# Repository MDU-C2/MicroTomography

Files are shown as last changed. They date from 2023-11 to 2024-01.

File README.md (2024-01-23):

# Microwave Imaging



## Install python packages from requirements.txt

Run the command

```console
pip install -r requirements.txt
```

In the command prompt

# Setup
First, make sure the following is powered on and set up as described.
## Router
- Connect the router to the eduroam network using an ethernet cable from the wall to the router.
- Connect the Raspberry Pi to the router using an ethernet cable.
- Connect the Network analyzer to the router using an ethernet cable.
- Connect the robot controller to the ruter using an ethernet cable.
- Power on the router by connecting it to a power outlet.

## Raspberry Pi 4
Set up the Raspberry pi:
- Connect the screen to the Pi using a micro-HDMI to HDMI cable.
- Connect the mouse and keyboard to the Pi using the USB-A conncetions.
- Connect a ethernet cable from the raspberry Pi to the router.
- Connect the USB-A side of the laser connection to a USB-A port on the Raspberry Pi
- Power on the Raspberry Pi by connecting the USB-C side of a Raspberry Pi 4 adapter to the Raspberry pi and the other side to a power outlet.

## Network Analyzer
- Connect the Microwave applicator to channel 2 on the network analyzer.
- Connect the Microwave reciever to channel 3 on the network analyzer.
- Connect the Lan 1 port of the network analyzer to the router using a ethernet cable.
- Conncet the power cable from the network analyzer to a power outlet.
- Make sure the switch by the power input is fliped to the on state.
- Power on the network analyser by pressing the on button in the lower left corner of the front panel. 

## Robot controller
- Connect the robot controller to the router using an ethernet cable.
- Connect a power cable from the robot controller to a power outlet.
- Power on the robot controller.

# Starting the program
There are two program to run. One is a terminal program and the other is a GUI, however, both lets you use the whole system. Both are located in the folder repositories/MicroTomography.

## Starting the terminal program
To start the terminal program follow these simple steps.
1. Follow the setup described above.
2. Locate the repositories/MicroTomography folder in the raspberry pi 4. This can be done by opening a new terminal window and typing `cd repositories/MicroTomography`.
3. Start the program main.py by typing `python3.10 Main.py` in the terminal window.

## Starting the GUI
To start the GUI follow these simple steps.
1. Follow the setup described above.
2. Locate the repositories/MicroTomography folder in the raspberry pi 4. This can be done by opening a new terminal window and typing `cd repositories/MicroTomography`.
3. Start the program main.py by typing `python3.10 MainProgram.py` in the terminal window.

# Move linear actuator and take measurements
To only move the linear actuator and take measurements at the current configuration of the robot run the file *take_measurements.py* where you get a prompt asking what you want to do. It saves the microwave data in both s2p and csv format.

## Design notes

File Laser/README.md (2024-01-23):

# Using the laser
## Setup
To use the laser simply connect the USB to the computer and take note of what port you connected to (on the raspberry pi it is usually /dev/ttyUSB0). You can then connect to the laser by calling the class:
``` python
from laser.optoNCDT1402 import optoNCDT1402

laser = optoNCDT1402("/dev/ttyUSB0")
```
This connects the laser to the computer via serial.
## Take measurements
To measure the distance with the laser, first make sure that it is on by connecting the laser off pin to ground then calling the measure() method:
``` python
from laser.optoNCDT1402 import optoNCDT1402

laser = optoNCDT1402("/dev/ttyUSB0")

distance = laser.measure()
```
This can easily be modified to takea measurement value every second:
``` python
from laser.optoNCDT1402 import optoNCDT1402
from time import sleep

laser = optoNCDT1402("/dev/ttyUSB0")
while True:
    distance = laser.measure()
    sleep(1)
```

## Get info and change moving average
Information about the laser can be recieved using getInfo():
``` python
from laser.optoNCDT1402 import optoNCDT1402

laser = optoNCDT1402("/dev/ttyUSB0")
print(laser.getInfo())
```
The internal moving average can also be changed by calling the setMovingAverage() method:
``` python
from laser.optoNCDT1402 import optoNCDT1402

laser = optoNCDT1402("/dev/ttyUSB0")
laser.setMovingAverage(10)
print(laser.getInfo())
```
The Filter Type should then read moving average and the Filter Number should read 10.

# optoNCDT1402-100 Class documentation
This document explains how to use the distance measurement sensor optoNCDT1402 and all of its functionalities.
The class needs the library pyserial 3.15. To install the library run the command
``` console
pip install pyserial
```
or the command
``` console
pip install -r requirements.txt
```
in the command prompt.

## Initialize class:
To initialize the class write optoNCDT1402() if the default parameters are correct. If not, the parameters comPort and noMeasurements can be added to the class call such that it becomes optoNCDT1402(comPort, noMeasurements).

### Parameters

**comPort:** A string with the name of the port on the computer the laser is connected to.

**noMeasurements:** The number of measurements to be averaged over before returning the distance. If you do not require averaging set it to 1 or leave it blank.
## Get laser info:
In the class you can retrieve the information stored in the laser. It will return in the form of a string and look something like

>ILD 1402: Standard <br> 
>A/N: 4120154 <br>
>O/N: 000 <br>
>S/N: 1234570 <br>
>MR: 50 <br>
>SoftVer: 1.001.796 <br> 
>BootVer: 1.001.16 <br>
>Date: 09/01/23 <br>
>Out Channel: analog | digital <br>
>Analog Error: last value | error value | error value after cycles xx //xx is 2 up to 99 <br>
>Filter Type: moving average | median<br>
>Filter Number: xx //with moving average xx is 1 up to 128, with median xx is 7, 5, 7 or 9<br>
>Scanrate: xxHz //xx is 1500 Hz, 1000 Hz, 750 Hz, 375 Hz<br> 
>type of digital output: binary | ascii <br>
>mode of analog/digital output: continuous | time | trigger<br>
>output time: xx //xx is time in ms 1<br>
>key status: unlock | lock | auto lock <br>
>mode of save setting: no save | save at each time<br> 
>mode of extern input: as teach in | as output trigger<br>
>peak searching: global maximum | first peak | last peak <br>
>Teach value 1: xx //xx is 1.0 up to 16368.0 <br>
>Teach value 2: xx //xx is 1.0 up to 16368.0<br>

To get the string, call optoNCDT1402.getInfo()

## Set moving average:
The laser have a function to set the Filter Type to moving average and the Filter Number. This means that a moving average of the last xx measurements are returned from the laser. This function can be set with the optoNCDT1402.setMovingAverage() call and returns True if it succeded or False if it did not. The parameter averagingNumber can be set to an integer to set the number of measurements to average over in the moving average.

### Parameters

**averagingNumber:** An int defining the number of measurements to average over in the laser

## Turn laser on/off:
The laser can be turned on or off from the class using the calls optoNCDT1402.laserOff() to turn off and optoNCDT1402.laserOn() to turn on. They both return True if it worked and False if it did not. The small black cable called laser_off needs to be grounded for the calls to work properly.

**The calls are volitile! The laser will always be on after disconnecting power!**

<span style = "color:red">**ALWAYS ASSUME THE LASER TO BE ON WHEN STARTING. DO NOT LOOK INTO THE LASER**</span>

## Get measurements:
To get measurements from the laser, call optoNCDT1402.measure(). This will start the measuring process by collecting two bytes from the laser and combining them to one difital number. The function then converts it to a distance in mm or an error string based on that digital number.

### Returns
Error or distance in mm

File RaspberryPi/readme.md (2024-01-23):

# Raspberry Pi

The following code will control the transistor which is connected to a GPIO pin on the Raspberry Pi. Depending to which GPIO pin the transistor is connected to the code may have to be mmodified to match the pin number.

> **_NOTE:_**  All code will be executed on the Raspberry Pi. The following code is used for controlling devices connected to the GPIO pins of Raspberry Pi.

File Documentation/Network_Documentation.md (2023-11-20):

# Network

The following documentation provides information regarding the network setup of the system. The network uses the 192.168.0.0/24 range

## Static IP addresses

Devices which are stationary to the system receives static IP addresses. Below is a list of the current devices allocated a static IP address.

* Wireless router: 192.168.0.1
* ABB Singe-Arm YuMi: 192.168.0.50
* Raspberry Pi: 192.168.0.51
* Vector Network Analyzer: 192.168.0.70

## Dynamic IP addresses

Clients which are not mentioned in the section above will receive an IP address from the range of 192.168.0.100-199

## WiFi

It is possible to connect to the network via WiFi

SSID: "*MW*"

Password: "*!UseThisPassword* "

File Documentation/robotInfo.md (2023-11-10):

# Robot Arm documentation - IRB 14050 Single Arm YuMi

This document is for information regarding the robotarm.

## Upload script to YuMi robot arm

Currently a slightly modified script of *SERVER.mod* is used , which can be found at <https://github.com/robotics/open_abb>. The modification done was from
*PERS string ipController:= "127.0.0.1";*
to
*PERS string ipController:= "192.168.0.100";* (the IP address will vary depending the on the address it is given by the DHCP server)

To upload the script to the YuMi controller you need RobotStudio. Ensure you are either:

* Connected to the YuMi via the MGMT port and that your PC has an IP address of 192.168.125.[2-254]. YuMi has an IP address of 192.168.125.1 which is static. Check connection from PC by opening a terminal and type "*ping 192.168.125.1*". If connection is established ping will be successful.
* Or connect the YuMi and your PC to a router that supports DHCP. When connecting the YuMi to router, use the WAN port on the YuMi. Find the allocated IP address of the YuMi by navigating to Settings -> Network settings on the YuMi FlexPendant. Check connection from PC by opening a terminal and ping the IP address found on the FlexPendant.

When connection has been established, open RobotStudio:

1. File -> Online -> One Click Connect
2. Open tab RAPID -> Program -> Load Module, upload "*SERVER.mod*". This will upload the module to the YuMi controller.
3. On the FlexPendant, navigate to *Operate*, select the uploaded file and press the physical *Play button* on the FlexPendant

## Joints range of motion

| Joint | Range (degrees) |
| ---  | --- |
| 1 | (-168.5) - 168.5  |
| 2 | (-143.51) - 43.49 |
| 3 | (-123.5) - 79.96  |
| 4 | (-289.95) - 289.84|
| 5 | (-87.62)  - 137.95|
| 6 | (-228.71) - 228.72|
| 7 | (-168.35) - 168.23|

## How to simulate the *IRB 14050 - YuMi* in *RobotStudio*

This section describes how the robot arm can be simulated in *RobotStudio* which is a preferable initial step for programming and testing the robot arm. To simulate the robot arm, open *RobotStudio* and perform the following steps:

1. Create a new project by *File -> New -> Station*.
2. Ensure that RobotWare 7.10 is installed. If not, navigate to the *Add-Ins* tab and find the package *RobotWare 7.10.0* and download it.
3. Create a new virtual controller by *Home -> Virtual Controller -> New Controller*
4. Select the *IRB 14050 0.5kg 0.5m* as the **Robot model** and choose the latest **RobotWare**. You can leave the rest unchanged, change the **Location** if you want to save the new controller in a different location than the default location.
5. When a pop-up window appears, select *IRB14050_0.5_0.5__03* and press **OK**.
6. To upload *RAPID* code to the virtual controller navigate to *RAPID -> Program -> Load Module* and upload the *RAPID* code you wish to execute. If you receive Errors after you have uploaded the code it might be due to there existing to *MAIN* files. In the tree structure to the left remove any *RAPID* files which you have not uploaded. To check if any errors persist press *RAPID -> Check Program* and check the log.
7. To start the simulation navigate to *Simulation -> Play*. *Do note that the simulation will not start if errors exist in the code
8. If you are sending commands to the robot arm via socket communication like this project. Ensure that the IP address in the *RAPID* and *Python* code are set to *127.0.0.1*  

## Potential issues and how to solve them

This section is for listing issues that has occured during the use of the arm whilst working with it during this project. Find potential issues here and how they were solved.

### Socket error

If the FlexPendant reports that you have a socket connection error which prevents you from connecting to the socket, the internal firewall of the Controller might be blocking it. This error may occur if you factory reset the controller. To fix the issue, try the following.

1. Connect your PC to the MGMT port of the controller and change your IP address to an address in the following range *192.168.125.[2-254]* with a subnet mask of *255.255.255.0*
2. Open *RobotStudio* and connect to the controller as specified in Section: **Upload script to YuMi robot arm**.
3. In *RobotStudio*, open *Controller -> Configuration -> Communication*. Open the tab *Firewall* and ensure that the desired connections are allowed through the Firewall. After changes are applied the controller needs to be restarted for the changes to be applied

### TimeoutError: timed out

If you are trying to connect to the robot via a TCP socket and receive a timeout error it is most likely due to networking issues. Check the following if you encounter this issue.

* Open the terminal on your computer and ensure you can ping the IP address of the controller.
* Make sure the IP address set in the *RAPID* code is the same as the IP address of the controller.
* Make sure the IP address set in the *Python* code is the same as the IP address of the controller.

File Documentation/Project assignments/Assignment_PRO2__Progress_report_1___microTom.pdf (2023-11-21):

# Progress Report 1-µTomography

Ihsan Haidari∗

, Joel Josefsson†

, Märta Krönström‡

, Dennis Landré§

, Filip Lindhe¶
, Jiantao Shen∥
, Samuel Wågbrant∗∗
School of Innovation, Design and Engineering Mälardalens University, Västerås, Sweden Email: ∗mhi19005, †

jjn17015, ‡mkm18003, §dle18001, ¶fle16001, ∥ jsn19012, ∗∗swt19001@student.mdu.se

I. PROJECT INFORMATION
Project title | Client Sponsors | Project Team Leaders | Project Date
Microwave Imaging for Breast Cancer Detection: A Non-Contacting Approach | Nikola Petrovic and Cristoph Salomon | Software: Märta Krönström Hardware: Dennis Landré | 2023-10-30
Name | Title | Responsibilities
Dennis Landré | Hardware Team Leader | Ensuring the project meets hardware requirements. 3D Modeling.
Ihsan Haidari | Hardware Developer | Responsible for the platform and sender platform.
Märta Krönström | Software Team Leader

Ensuring the project
meets software
requirements.
Responsible for
simulations.
Joel Josefsson | Software Developer

Responsible for the
Laser and distance
measurements. 3D
scanning patterns
and Git.
Filip Lindhe | Software Developer | Responsible for the surface reconstruction
Jiantao Shen | Software Developer | Responsible for the GUI
Samuel Wågbrant | Software Developer | Responsible for YuMi and control systems.

II. SHORT PROJECT PROGRESS SUMMARY

This project is on track and so far, no substantial obstacles have been encountered. There are only a few delayed work packages and more information about which ones can be found in Section III and their recovery plan in Section VI. In relation to the planned scope, the team has almost completed the subgoal of automating measurements for an object with known symmetric geometry. The last big part of that component will be to include measurements with the microwave sensors.
The next steps for the software team are to continue optimizing the laser measurements, integrate all the functionality on the central control unit and GUI, and start working with the microwave measurements. For the hardware team, it is to place all the equipment and manage the cables for the central control unit and platform.
For more information about the status of each work package, see Section II and details about them in Section III. There is also a plan to perform some tests in regard to controlling the calibration of the robot arm as a potential risk is that it is not accurate. For more specifics about this look at section VII.

III. WORK PACKAGE STATUS

Table I
THIS TABLE OUTLINES THE STATUS OF EACH WORK PACKAGE TOGETHER WITH THE DATE WHEN EACH PACKAGE SHOULD BE COMPLETED.
ID | Work package | Deadline | Planning Status | Completion Status
1.1.1 | Robot arm | 17/9-23 | On track | In Progress
1.1.2 | Platform | 17/9-23 | Off track | In Progress
1.1.3 | Sender platform | 31/10-23 | On track | Completed
1.1.4 | Robot tool/end-effector | 1/10-23 | Off track | In Progress
1.1.5 | Breast phantoms | 1/10-23 | On track | In Progress
1.1.6 | Central control system | 15/10-23 | Off track | In Progress
1.1.7 | Network | 22/10-23 | On track | Completed
1.1.8 | GUI | 5/11-23 | On track | In Progress
1.2.1 | Laser | 3/12-23 | On track | Completed
1.2.2 | Microwave measurements | 3/12-23 | On track | In Progress
1.2.3 | Surface reconstruction | 14/12-23 | On track | In Progress
A. Robot arm

The ABB Single-Arm YuMi®
IRB 14050 [1] is used for
the initial scan of the breast phantom and to move the microwave antenna to the desired location during the microwave measurements.
1) Simulations: A standard test station has been created for the simulations, including obstacles such as the platform for the robot arm, the sender platform, and the breast phantom 1(a). An end-effector has been defined using a CAD model of the new tool. Three Tool Center Points (TCPs) have been defined; one for the antenna, one for the laser, and one used for calibration 1(b). The data for these TCPs can then be used to decide which tool to use. Further, collision sets have been created to be able to visualize any collisions. This can hence be used for controlling and testing the planned paths.
2) Communication: Communication between the Raspberry Pi and the YuMi is handled via a Transmission Control Protocol (TCP) socket connection where the YuMi will act as a socket server waiting for incoming commands from

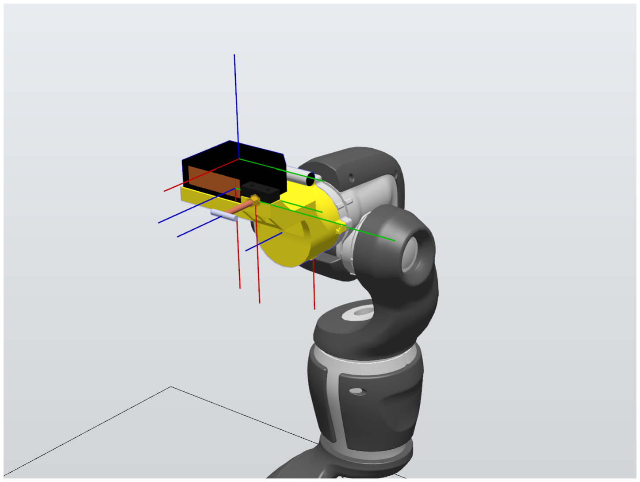
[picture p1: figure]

(a) Simulation station | (b) End-effector

Zone 1

Zone 3 | Zone 4

Zone 2

x

y

Figure 1. The logical zones created to plan the path of the robot. The zones are created to force the robot to travel sequentially through the zones to avoid collisions with the environment and to adjust the angle of the robot arm to optimize it to the current zone.

the Raspberry Pi. This is done via a Python program on the Raspberry Pi and an ABB Rapid program on the YuMi.
3) Path planning: A cylindrical pattern has been created as a path for the laser measurements where the z-axis of the laser always points inwards to the (0, 0) point in the plane. Another option has been made where the laser points upwards at a specific angle but always pointing inwards. Four different zones have been logically created to position the YuMi in a desired location when travelling to a position so as not to hit any equipment, see Figure 1. When travelling to a position that is placed in a different zone relative to the current zone, the YuMi will be forced to sequentially travel through zones to reach its new target position. The YuMi has been restricted from travelling directly from Zone 1 to Zone 4 to avoid reaching its joint limits. Continuing forward, the positioning of the joints needs to be refined in such a way that cables and equipment connected to the YuMi are not damaged or tangled when the YuMi is moved from one position to another.
4) Testing: The robot arm has successfully been tested both outside and inside of the new frame. Before each run, the paths have been simulated and confirmed to not collide with the environment. This testing will continue for both laser measurements and microwave measurements.
5) Next step: The next step for the robot arm is to develop a pattern for the microwave measurements. Also, to keep on testing with the laser.

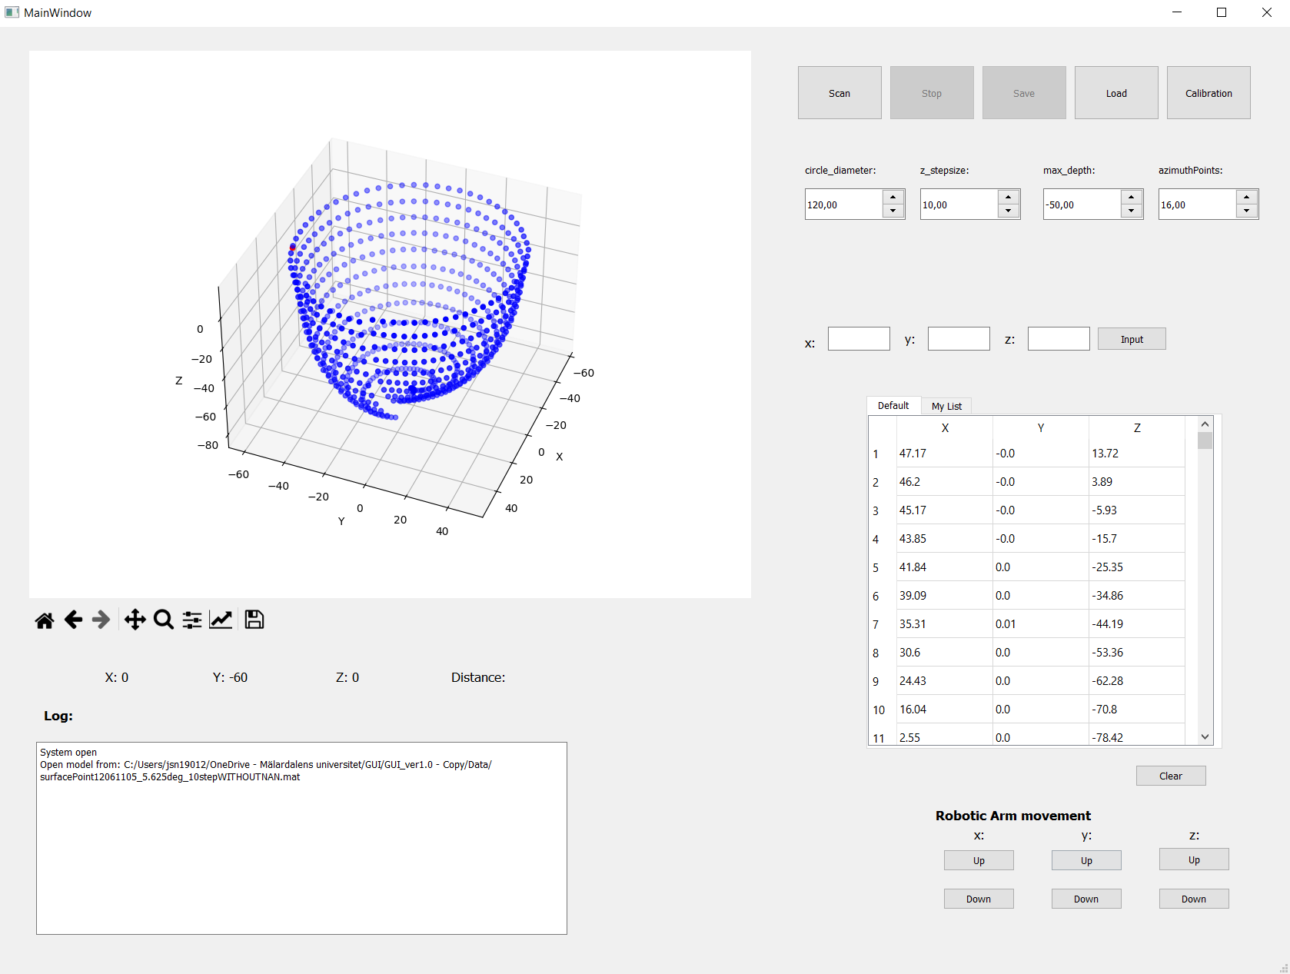
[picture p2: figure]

Figure 2. The figure shows the current UI design. Users can scan objects, save and load scan data simply by pressing the corresponding buttons. The system will automatically create a scan list based on circle_radius, z_stepsize, max_depth and azimuthPoints. Additionally, the scan results will be plotted on a chart and displayed in a table. Users can also create their own scan lists. Furthermore, users are able to move YuMi manually using GUI.

B. Graphical User Interface

A Graphical User Interface (GUI) has been created, which includes functionality that meets the basic requirements of the project, such as scanning, saving, and reading scanned data in files, and displaying plots of scanned data. Figure 2 shows the design of the GUI, but it will be modified when more features are completed. Figure 3 shows the operation process of different buttons and what features have been completed so far.
The idea of the GUI is that when you press the scan button, the system will automatically connect YuMI and the laser and perform scanning. The scanning is based on circle_radius, z_stepsize, max_depth and azimuthPoints values. Once the scanning is completed, the scanning points will be plotted on the chart and values will be displayed on the "default" table. The 3D reconstruction will be displayed in a new window. You can stop the scanning by pressing the "stop" button. You can also save and load the data in a file. Furthermore, you can create your own scan list by inputting x, y, and z values on the "mylist" table. You can also move the laser to a specific point and point it at the model’s surface. The calibration button is used to calibrate the origin of the system.
1) Next step: The plan for the GUI is to complete all the functions in Figure 3 and test them in Raspberry Pi. Once the GUI is working properly, more advanced features such as changing the laser angle will be implemented.
C. Platform

The platform is constructed using Medium-Density Fibreboard (MDF) and aluminium profiles as shown in Figure 4. A hole has been carved out on the top level of the plat-

MÄLARDALEN UNIVERSITY | Page 2 of 31 | 2023/10/27

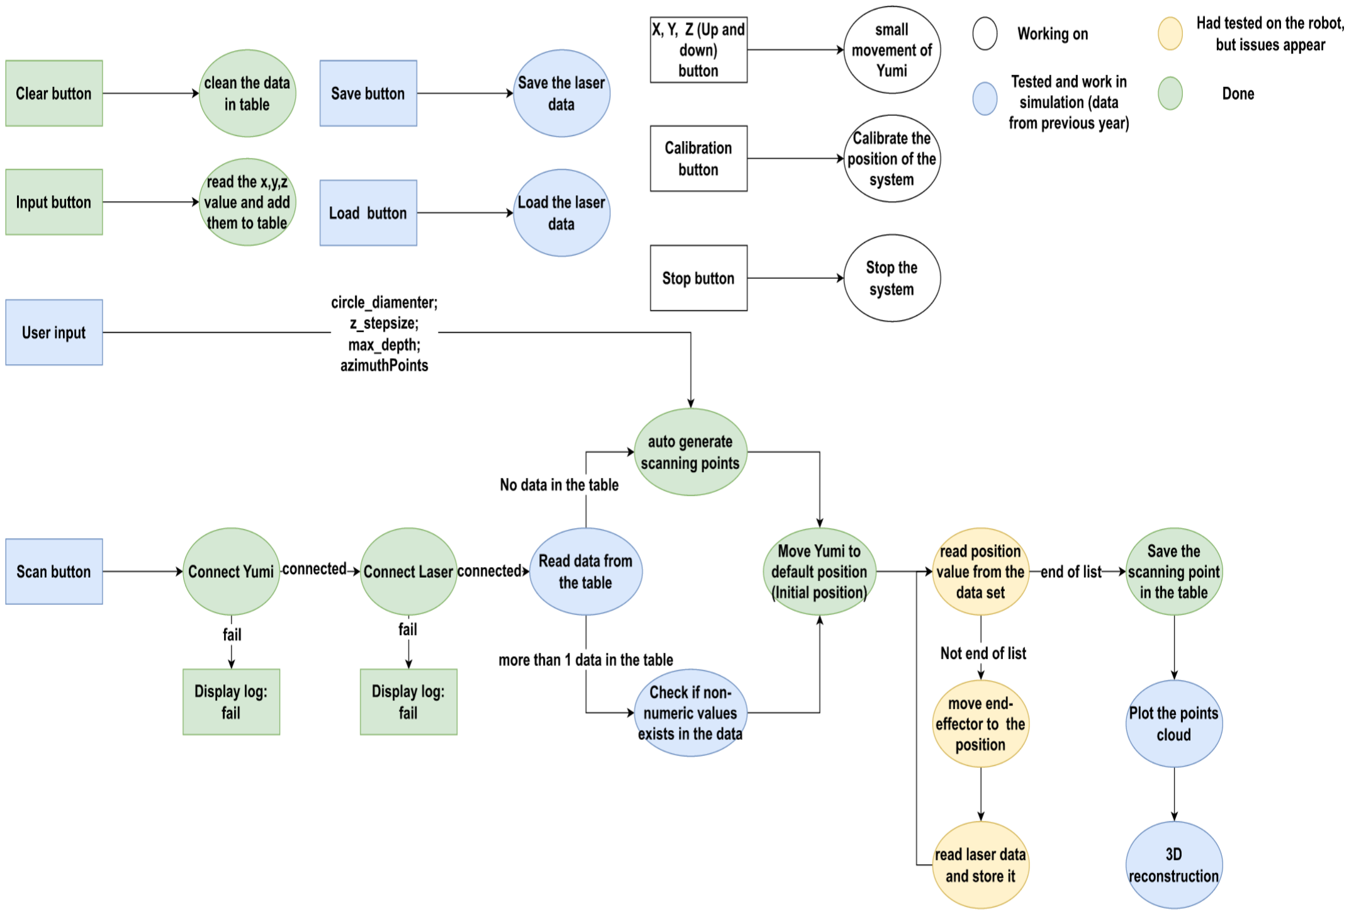
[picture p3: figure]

Figure 3. This diagram shows what features have been completed so far.

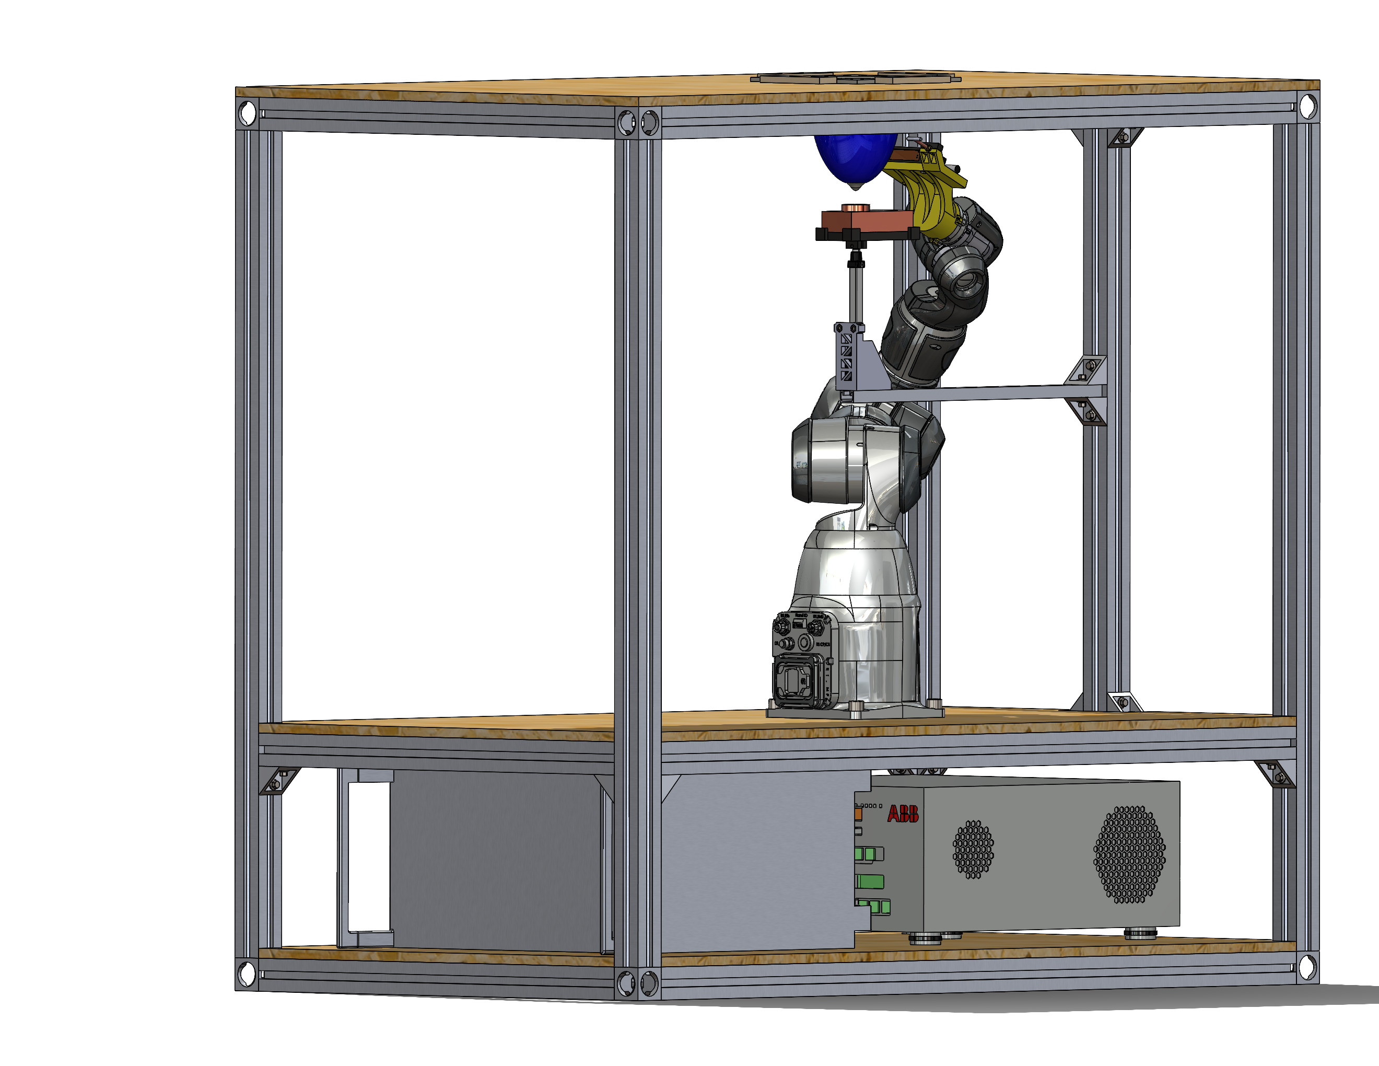
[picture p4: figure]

Figure 4. Platform

form and it is centred to accommodate the robot arm for suspending the breast phantom.
Modifications have been made to the initial design, including changing the sender platform. The previous sender platform was mounted to the lower surface under the breast phantom, preventing the robot arm from reaching around the breast phantom. The updated design, which is affixed to the side of the platform makes it possible for the robot arm to reach around the breast phantom, and also it offers increased stability, reduced noise level, and smaller step size. The next steps for this work package are placing all the equipment on the platform and cable management.
D. Sender platform

The sender platform comprises a microwave transmitter, a linear actuator [2], a stepper motor driver [3], and a step-down module [4]. The transmitter is mounted on the top of the linear actuator, allowing it to move in a range of 100 mm depending on the dimensions of the phantom. The step-

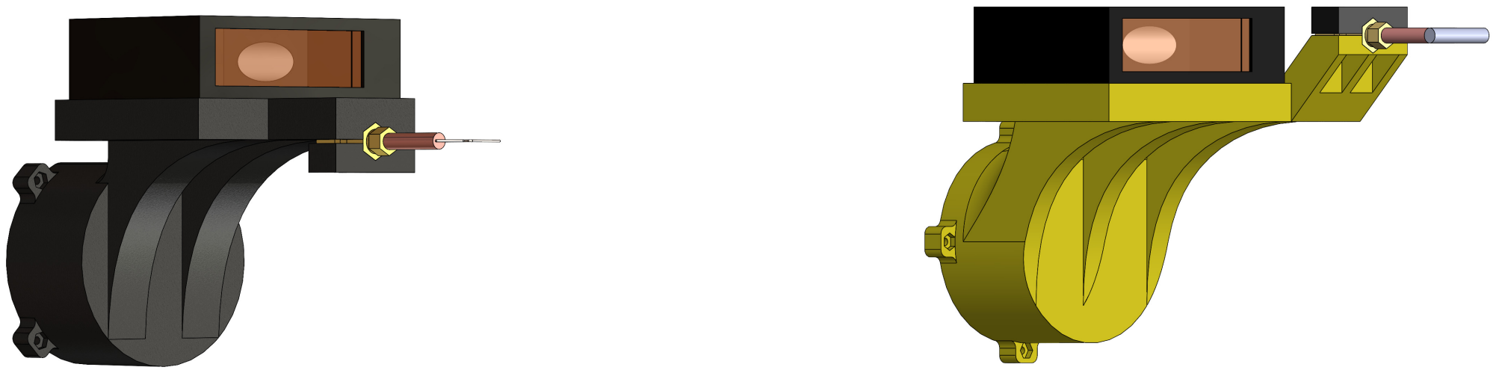
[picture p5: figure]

Figure 5. End-effectors with laser distance sensor and applicator mounted. The current version (black) has the applicator mounted below the laser sensor and the new version (yellow) has the applicator mounted next to the laser sensor.

down module is used to reduce the voltage from 20V to 3.3V, serving as the power source for controlling the linear actuator signals. An external power source is preferred over Raspberry Pi’s power source due to its efficiency and it poses no damage to Raspberry Pi. The linear actuator has a step size of 0.01 mm, fulfilling its intended purpose by positioning the transmitter at a desired distance from the phantom. As of now, it is equipped with four functions: Ascending to a specified distance, descending to the zero position, ascending or descending by 1 mm. The functions are not final and they can be modified if it is needed. The next step is to integrate the functions into the GUI and test the performance of the sender system.

E. Robot tool/end-effector

Figure 5 shows the current and the new design of the end-effector. The initial design was reworked as the applicator could not reach the upper parts (the base) of the phantom, at a right angle, as the laser sensor interfered with the ceiling of the platform. By keeping them at the same height, the laser and the applicator should have the same reachability. The next step in this work package is to 3D-print the tool and mount the sensor and applicator.

F. Breast phantoms

Symmetrical breast phantoms have been 3D-printed, in two different variants with different dimensions. The next step for this work package is to 3D-print asymmetrical phantoms based on some dimensions and images obtained from the stakeholders.

G. Central control system

Evaluation of the old control units (Arduino and Beagle Board) has been made and it was decided that it was best to change for increased performance. A new control unit in the form of a Raspberry Pi 4B [5] has been obtained. The team has started setting up everything on the Raspberry Pi, such as git, downloading necessary packages, creating a shell for all the functionality, etc. A control system box has been designed to house the Raspberry Pi, power supplies, motor controller, laser sensor cable adapter, and custom circuit boards. The next step for this work package is the cable management for the sensors, actuators, and robot arm.

MÄLARDALEN UNIVERSITY | Page 3 of 31 | 2023/10/27

Table II
TABLE SHOWING THE RESULT OF THE MANUAL TESTING OF THE OPTONCDT
1402
True distance (mm) | Measured distance (mm) | Error (mm)
150 | 150.87 | 0.87
140 | 140.77 | 0.77
130 | 130.42 | 0.42
120 | 120.97 | 0.97
110 | 110.60 | 0.60
100 | 100.30 | 0.30
90 | 90.37 | 0.37
80 | 80.42 | 0.42
70 | 70.18 | 0.18
60 | 60.42 | 0.42
50 | 50.24 | 0.24
H. Network

All devices, excluding the laser, communicate with each other via Ethernet. For this reason, a Local Area Network (LAN) has been created to enable communication between all devices. Devices that are stationary to the system are allocated static IP addresses within the network.

I. Laser

The Distance measurement sensor used is the optoNCDT 1402-100 [6]. The measured data arrives via a serial port to the connected computer. Each measurement consists of two consecutive bytes of 8 bits each. One has 1 as the biggest bit and the other 0. These two are combined into one 14-bit number and the distance from the sensor can be determined by equation 1

d i st ance(mm) = 50+

µ
do ∗

1.02
16368

−0.01¶
∗100 (1)

where do is the combined bits.
Code has been implemented to connect via serial to the sensor, to measure and calculate the distance, to set the internal measurement mode to moving average, and to turn the laser off and on via the serial port. However, turning the laser on and off by writing via serial proved to be unreliable as the message did not always get received. A solution has been made to include a transistor circuit to turn the laser on and off between measurements. For extra safety, a physical switch is put in series with the transistor circuit which decides the absolute state of the laser.
The data from the laser is then transformed to the point of the end-effector for all points which creates a point cloud of the scanned breast.
The laser have been tested by measuring distances from 50 mm to 150 mm in intervals of 10 mm using a ruler on a straight piece of wood. Another solid piece of wood was prompted up against the end where the 0mm line is. The optoNCDT 1402 was manually placed on each line and a measurement was taken. The result of the testing can be seen in Table II.
Six different test measurements were conducted one after the other to test the repeatability of the current robot/laser setup. The robot was set up to take measurements on 4

Table III
TABLE SHOWING VARIANCE IN THE DIFFERENCE BETWEEN EACH MEASUREMENT WHEN COMPARED TO THE FIRST MEASUREMENT.

Measurement Variance in X(mm²
)
| | Variance in Y(mm²
)
| | | Variance in Z(mm²
)
1 | 0.003 | 0.0006 | 0
2 | 0.002 | 0.001 | 0
3 | 0.002 | 0.001 | 0
4 | 0.003 | 0.001 | 0
5 | 0.003 | 0.001 | 0

Table IV
TABLE SHOWING MIN AND MAX VALUE IN THE DIFFERENCE BETWEEN EACH MEASUREMENT WHEN COMPARED TO THE FIRST MEASUREMENT.
Measurement | Min/Max difference in X(mm) | Min/Max difference in Y(mm) | Min/Max difference in Z(mm)
1 | 0/0.32 | 0/0.12 | 0/0
2 | 0/0.16 | 0/0.16 | 0/0
3 | 0/0.19 | 0/0.18 | 0/0
4 | 0/0.25 | 0/0.17 | 0/0
5 | 0/0.22 | 0/0.19 | 0/0

points on each of the 8 azimuth angles. The data was gathered and the five last measurements were each compared to the first measurement. The variance and difference between each measurement were calculated and can be seen in Table III and Table IV.
1) Next step: This package can be seen as done but some more testing could be done, specifically test how good the measurement is at an angle, if the time and resources allow for it.
J. Microwave measurements

The network analyser has been obtained, and the group has started getting familiar with it as well as testing communication, etc. The next step for this work package is to obtain the sensors (receiver and transmitter) and test using them. Also, to get a more thorough introduction from the supervisors.

K. Surface reconstruction

Four different surface reconstruction algorithms have been implemented and tested on the previous year’s measured data. The four algorithms are : Alpha shape [7], Ball-pivoting algorithm [8], Cocone [9] and Poisson surface reconstruction [10]. Based on some simple tests using the aforementioned data it is concluded that cocone or poisson surface reconstruction algorithms will be used since Alpha shape and ball-pivoting algorithm did not produce watertight meshes.
Cocone works by performing a Delaunay tetrahedralization of an input point cloud, where the Delaunay tetrahedralization partitions the point cloud into non-overlapping tetrahedra, while ensuring that no input point lies within the circumsphere of any other tetrahedron. The algorithm then classifies all the tetrahedra as either inside point, outside point or surface tetrahedra, where the surface
MÄLARDALEN UNIVERSITY | Page 4 of 31 | 2023/10/27

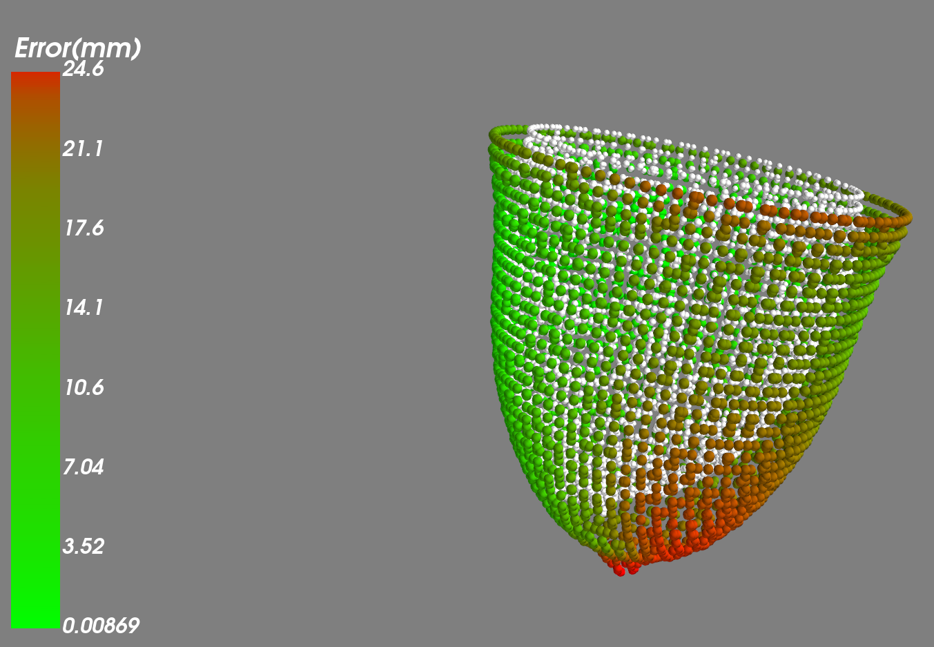
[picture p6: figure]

Figure 6. Showing each starting point of the raytracing as coloured dots, where the colour indicates the error in the distance and the white dots is the point cloud created from the reconstructed mesh.

tetrahedra is the classification that is relevant for the surface reconstruction. For each of the surface tetrahedra, the algorithm constructs a hierarchical structure that describes the local surface geometry, this hierarchical structure is called a "Cone-Tree". The algorithm then traverses all Cone-trees and connects the surface tetrahedras to form a continuous mesh.
The Poisson surface reconstruction works by first estimating the normal vectors at each point in the point cloud. After this, a 3D grid is placed over the entire space containing the point cloud, and each voxel in the grid is associated with a scalar value which is initially set to 0. The algorithm then sets up a Poisson equation for the scalar values of the voxels. The equation involves Laplace’s equation which describes how the scalar value at each voxel relates to the values of its neighbours. The Poisson equation is weighted based on the estimated normal vectors as seen in equation 2

∇

2φ = −∇(n) | (2)

where ∇

2
is the laplacian operator, φ is the unknown surface, ∇ is the gradient operator and n is the estimated normal vector. When the Poisson equation is found the algorithm solves said equation, then uses an isosurface extraction technique to extract the surface. To implement Poisson surface reconstruction, a Python library called Open3d [11] was used.
An error estimation algorithm has been implemented using a raycasting method where it is possible to measure the distance from a point to the reconstructed mesh and thus measure how the reconstructed mesh differs from the CAD model used to create the known geometrical breast phantom.
1) Next step: When additional data have been collected further testing will be made to see which of the two algorithms produces the best results. Based on the results of these tests a decision will be made on which of the algorithms will be used in the final product.

IV. COMPLETED ACTIVITIES AND UPCOMING ACTIVITIES

The following section details the completed activities and upcoming activities found in the project plan, see Appendix A.

A. Completed

The following list is based on the Work Breakdown Structure (WBS) and contains all the completed deliverables, work packages, and tasks. This means that if a work package is stated then all of the deliverables and tasks within it are completed (hierarchical order).
- 1.1.1.1 Deliverable Control of the robot arm
- 1.1.1.2.1 Task Test outside of frame
- 1.1.2.1.1 Task Mount all the boards and aluminium profile
- 1.1.2.1.2 Task Adding features for robustness
- 1.1.2.1.3 Task Safety features
- 1.1.2.1.6 Task Hole for breast phantom
- 1.1.3 Work package Sender platform
- 1.1.4.1.1 Task Evaluation and comparison of last iterations tool
- 1.1.4.1.2 Task Fit laser and antenna
- 1.1.4.1.3 Task Designing
- 1.1.4.1.6 Task Get dimensions of the microwave antenna
- 1.1.4.1.7 Task Print antenna for testing
- 1.1.5.2.1 Task Get the required dimensions
- 1.1.5.3 Deliverable Holder for phantoms
- 1.1.6.1.1 Task Evaluation of Beagle Board vs. Raspberry Pi
- 1.1.6.1.2 Task Possibly transition to Raspberry Pi
- 1.1.7 Work package Network
- 1.1.8.1.4 Task Buttons for control of laser measurements
- 1.1.8.1.5 Task Buttons for control of the microwave measurements
- 1.1.8.1.6 Task Visualisation of the measurements
- 1.2.1 Work package Laser
- 1.2.2.1 Deliverable Get familiar with the equipment
- 1.2.2.1.1 Task Obtain the equipment
- 1.2.2.1.2 Task Get introduction from supervisors
- 1.2.3.1 Deliverable Implement algorithms
B. Upcoming

The following list is also based on the WBS and includes the upcoming activities within the project.
- 1.1.1.2.2 Task Test inside of the frame
- 1.1.1.3 Deliverable Documentation
- 1.1.2.1.4 Task Equipment placement
- 1.1.2.1.5 Task Cable management
- 1.1.2.4 Deliverable Documentation
- 1.1.4.1.4 Task 3D-Printing
- 1.1.4.1.5 Task Mounting
- 1.1.4.2 Deliverable Documentation
- 1.1.5.1 Deliverable Old phantoms
- 1.1.5.2.2 Task 3D-print prototypes
MÄLARDALEN UNIVERSITY | Page 5 of 31 | 2023/10/27

- 1.1.5.3 Deliverable Documentation
- 1.1.6.2 Deliverable Connection management
- 1.1.8.1.1 Task Emergency stop button
- 1.1.8.1.2 Task Buttons for control of robot arm in different coordinate systems
- 1.1.8.1.3 Task Buttons for control of sender platform
- 1.1.8.1.7 Task Visualisation of results
- 1.1.8.1.8 Task Controls with manual control similar to the joystick on the controller
- 1.1.8.2 Deliverable Documentation
- 1.2.2.2 Deliverable Functionality for the measurements
- 1.2.2.2.1 Task User can choose area
- 1.2.2.2.2 Task Scanning points based on given positions
- 1.2.2.2.3 Task Move transmitter and receiver to defined positions
- 1.2.2.2.4 Task Perform measurements
- 1.2.2.2.5 Task Save data
- 1.2.2.3 Deliverable Documentation
- 1.2.3.2 Deliverable Evaluate algorithms
- 1.2.3.3 Deliverable Documentation
V. ACCOUNTABILITY FOR OFF-TRACK WORK PACKAGES

The responsible for the work packages 1.1.2, 1.1.4, 1.1.5, and 1.1.6 is the hardware team.

VI. RECOVERY PLAN FOR OFF-TRACK WORK PACKAGES

A lot of the work packages are in fact ahead of their planned timelines and can therefore compensate for some of the ones falling behind.

A. 1.1.2 Platform

For the platform what is left is placing all the equipment on the platform and cable management. For this, resources will be reallocated to fix it.

B. 1.1.4 Robot tool/end-effector

A second iteration of the Robot tool is under development and will be completed during week 43.

C. 1.1.5 Breast phantoms

The asymmetrical phantom should be printed. There is no current need for it and therefore more time can be allocated to finish it.

D. 1.1.6 Central Control System

For the control system, cable management is what remains. This package is a priority and hence, resources will be reallocated to fix this.

VII. ISSUES, BLOCKERS AND RISK STATUS

A potential risk could be the current calibration of the robot arm. The team had to re-calibrate it by updating the revolution counters [12] and this could have affected the precision of it. The steps for calibration were followed, meaning that all the axes marks were set into place and then the counters were updated. When testing there has been some offset from the expected results and this might be because of the calibration.

The first step to control if this is an actual risk was to test the accuracy and precision of the robot arm by using the laser. This showed that the repeatability was good. The accuracy was a bit off and this is something that could be compensated by the software, but ideally, the robot arm would need to be checked. The group is working on getting in contact with someone on ABB who could possibly control if the calibration is accurate. Even if the measurements indicate that the precision is correct it could be good to get it checked.

VIII. INDIVIDUAL CONTRIBUTIONS

A. Ihsan Haidari

Have been working on the sender platform including the step-down module, the code for the linear actuator, the design of the system, and the testing. Also partially working on the platform including construction of the platform and cooperating with the designing and printing of the 3D parts.

B. Joel Josefsson

Have been working on the laser, making the code for operating the laser and the transformation from distance to point cloud, setting it up and testing it. Made code for the path planning of the end-effector on the robot. Have started to look into the network analyser.

C. Märta Krönström

Have been working with the robot arm. Simulations and testing. Have also been responsible for team-leader work such as preparing material for meetings, planning, dividing tasks, documentation, and contact with stakeholders.

D. Dennis Landré

Have been designing the sender platform, electronics control box, end-effector tool, complete electronic circuit schematic, step down circuit, digital laser off switch circuit, breast phantoms, platform and calibration tool which have been 3D-printed, soldered or constructed. I have also ordered the necessary parts needed.

E. Filip Lindhe

Have been working mainly on the surface reconstruction work package, This includes researching viable surface reconstruction algorithms, implementing algorithms, and implementing an error metric algorithm which can be used to test the surface reconstruction algorithm.

F. Jiantao Shen

Have been working on the GUI side, creating the design of the GUI and connecting the completed functionality to the GUI.
G. Samuel Wågbrant

Have been working with the robot arm. This includes the communication between the robot arm and the connecting control system, ensuring the robot arm follows the determined path in a safe manner, and creating an interface to control the robot from the control system.

MÄLARDALEN UNIVERSITY | Page 6 of 31 | 2023/10/27

REFERENCES

[1] YuMi® IRB 14050, ABB, accessed: 20-10-2023. [Online]. Available: https://search.abb.com/library/Download.aspx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 (https://search.abb.com/library/Download.aspx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)
[2] RS Components. Electric linear actuator - rs components. Accessed: 23-10-2023. [Online]. Available: https://se.rs-online.com/web/p/electric-linear-actuators/2174863 (https://se.rs-online.com/web/p/electric-linear-actuators/2174863)
[3] Maker Guides. (2019) Tb6600 stepper motor driver manual. Accessed: 23-10-2023. [Online]. Available: https://www.makerguides.com/wp-content/uploads/2019/10/TB6600-Manual.pdf (https://www.makerguides.com/wp-content/uploads/2019/10/TB6600-Manual.pdf)
[4] PCHbutik. | Adjustable | dc-dc | step-down | volt-
age | converter | - | pchbutik. | Accessed: | 23-10-
2023. | [Online]. | Available: | https://pchbutik.se/en/volt-dc-dc/
226-justerbar-dc-dc-step-down-spannings-omvandlare-lm2596.html (https://pchbutik.se/en/volt-dc-dc/226-justerbar-dc-dc-step-down-spannings-omvandlare-lm2596.html)
[5] Raspberry Pi 4 Model B, 1st ed., Raspberry Pi (Trading) Ltd., June 2019. [Online]. Available: https://datasheets.raspberrypi.com/rpi4/raspberry-pi-4-datasheet.pdf (https://datasheets.raspberrypi.com/rpi4/raspberry-pi-4-datasheet.pdf)
[6] optoNCDT 1402, Micro-Epsilon, 2008. [Online]. Available: http: //www.micro-epsilon.pl/download/man--optoncdt-1402--en.pdf
[7] K. Fischer, “Introduction to alpha shapes.”
[8] F. Bernardini, J. Mittleman, H. Rushmeier, C. Silva, G. Taubin, and
S. Member, “The bal i-pivoting algorithm for surface reconstruction.”
[9] T. K. Dey and S. Goswami, “Tight cocone : A water-tight surface reconstructor *.”
[10] M. Kazhdan, M. Bolitho, and H. Hoppe, “Poisson surface reconstruction,” 2006.
[11] “Open3d,” accessed: October 1 2023. [Online]. Available: http: //www.open3d.org/
[12] ABB. (2023) Product manual irb 14050. Accessed on 25 October 2023. [Online]. Available: https://search.abb.com/library/Download.aspx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 (https://search.abb.com/library/Download.aspx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)

APPENDIX A
PROJECT PLAN

The original project plan can be viewed on the next pages.

MÄLARDALEN UNIVERSITY | Page 7 of 31 | 2023/10/27

# Project plan

Project title | Client / Sponsor | Project team leaders
Microwave Imaging for Breast Cancer Detection: A Non-Contacting Approach | Nikola Petrovic and Cristoph Salomon | Software: Märta Krönström Hardware: Dennis Landré

### 1 Executive summary

The research field for this project is Microwave Imaging (MWI) for breast cancer detection. In MWI, non-ionizing microwaves penetrate the surface, scatter throughout the object and reflect back to a receiver. An image can then be reconstructed based on the dielectric properties of the object. Since breast tumours have different dielectrics than healthy breast tissue, the image will show if any tumours are present in the breast.

This project is performed in close collaboration with the Biomedical Engineering Research group at Mälardalen University (MDU) [1]. During their research, they developed a sensor for MWI applications, specifically breast cancer detection, which uses electromagnetic waves in an efficient matter to irradiate the breast. To obtain the signal from this sensor, a receiver antenna must be employed, which should be moved closely around the object to measure the transmitted signal strength at different positions. For this purpose, the researchers acquired an ABB Single-Arm YuMi (SAY) collaborative robot where the end-effector is meant to contain the receiver [2].

The goal of this project is to be able to perform a series of automated microwave measurements using the previously mentioned equipment. The object to measure is a breast phantom and the goal can further be divided into two parts. The first part is to be able to measure a breast phantom with known geometry, and the next is to measure one with unknown geometry. The purpose of this project is to contribute to the ongoing research efforts of the project’s stakeholders. Specifically, to develop a non-contacting, non-ionizing breast cancer scanning system utilising MWI technology.

The main tasks of the project will be to set up the robot arm along with the other hardware provided. Furthermore, a Graphical User Interface (GUI) needs to be developed to move the microwave transmitter and receiver to defined positions around the breast phantom with known geometry. Moreover, laser-based surface estimation should be used to perform automated measurements on a breast phantom with unknown geometry.

### 2 Background

Breast cancer is the most common form of cancer in women. Statistics from the International Agency for Research on Cancer state that in 2020 around 25% of all new cases of cancer in women were breast cancer with 2 261 419 new cases and 684 996 deaths worldwide [3, 4]. World Health Organization also projects increases in new cases of breast cancer by up to 91.2% and death by up to 94.2% in 2020-2040 [5]. Early stages of breast cancer often appear as lumps in the breast with little to no other symptoms. These cancerous lumps can then spread cancer to the lymph nodes if left untreated. However, if caught before they spread, the tumours can be treated more successfully [6]. Thus, making the need for early detection prominent. The main screening method for detecting early breast cancer today is mammography where the naked breast is squeezed between two plastic plates and then X-rayed. This procedure can be both uncomfortable and sometimes painful [7]. Studies have shown that the main reason for not getting a re-screening when invited is that it was painful to do the first one [8, 9]. The ionizing radiation from the X-ray could also induce breast cancer in the patient which would cause more harm than benefit [10]. Clearly, a more comfortable, painless, and safe method must be developed.

One promising method to differentiate between healthy breast tissue and tumours in the breast is Microwave Imaging (MWI) [11]. The technique of MWI uses non-ionizing electromagnetic microwaves to develop internal images of the breast based on the electric properties of the breast tissue and the tumour. The microwaves penetrate through the breast, scatter, and reflect. These scattered, reflected signals are received and an internal image of the breast is constructed. Since the dielectric properties of malignant breast tissue differ from healthy breast tissue, the image will show if there are tumours present.

Commonly in MWI, an array of antennas is used around the breast to illuminate it with microwaves [12, 13, 14, 15, 16]. There are a few different methods to acquire signals from the setup. One popular method is Confocal Microwave Imaging (CMWI) [14, 15, 16]. This method is radar-based which only considers the reflected backscattering from the object using one antenna at a time. Another method is Microwave Tomography (MWT) [12]. This method considers

© ProjectBase 7.0 Baseline Management AB, 2018 | 1 | 2023-10-26

only the scattered signals transmitted from the object. These two methods also produce different images. CMWI is a more simple approach that attempts to identify the position of significant scattering in the breast. This can be done with beamforming algorithms such as Delay-Multiply-and-Sum [16]. MWT is a more complex method as it aims to use an inverse scattering method to get the diagnostic image of the breast. This method is calculation-heavy and requires image reconstruction algorithms to generate a map of permittivity and conductivity [11]. One popular way to get this is the Gauss-Newton method [17].

Since the difference in electrical properties between the air and the skin is so high the signals reflect early. These early-reflected signals can be quite large and can hide the reflected signals of the tumours. To mitigate these effects, researchers put the breast and the antenna array in a coupling medium. This is often a liquid with the same electrical properties as the tissue [12, 18, 19]. However, recently some researchers have developed a way to do MWI in a dry setup by mitigating the early skin reflection using Singular Value Decomposition (SVD) [20].

The research on MWI using breast phantoms at Mälardalen University (MDU) started in 2014 [21]. A receiving antenna was mounted on a robotic arm with six degrees of freedom. One identical antenna was mounted on the fixture which was placed in a pool filled with water as a propagating medium. A stepper motor was also mounted on the fixture that spins the object of interest to get imaging from different angles. The robotic arm with the receiving antenna was able to scan the object in a half-spherical, cylindrical, or planar manner around the object. The phantom used was a cylinder made from polycarbonate filled with deionized water and Troton X-100. Another, smaller cylinder of the same material but with salt added in the fluids was put inside the larger one to simulate a tumour.

In 2017, researchers at MDU theorised a new system designed to work in the open air instead of in a coupling liquid. They concluded that problems with surface waves can be avoided by using excitation devices [22]. They later designed a novel microwave applicator that is used without coupling liquids. This is done by designing the applicator to not couple energy into the air but directly into the breast [23]. In 2022 students at MDU worked on a system to be used with the applicator and an antenna. They used a Single-Arm YuMi (SAY) and a laser distance sensor to make a 3D model of a 3D-printed breast phantom. They also made a 3D-printed, motor-controlled moving platform for the microwave applicator to be positioned under the breast [24].

Collaborative robots or cobots are robots that collaborate with humans. These robots have successfully been implemented in several different industry settings [25]. Recently, they have also been implemented as a tool in the medical field to assist personnel with different tasks. Robot-assisted surgery is one field in which robots are used to assist the surgeon in performing minimally invasive surgery on patients [26, 27, 28].

ABB Robotics is well known for its wide variety of robots in various sizes and reach. One collaborative robot by ABB is the Single-Arm YuMi® IRB 14050, a one-armed descendant of the Dual-Arm YuMi introduced in 2015. It is designed with seven axes whose movements mimic that of a human arm. The robot is lightweight and has a small footprint making the position in which can be mounted flexible. The SAY is specifically made to work alongside humans, thus having the option of safety features such as ABB’s Safemode [2].

Surface reconstruction refers to the method of generating a soft copy of the data of an object given scanned data of the object [29]. The scanned data can be arranged in a few ways. One way is by having the input data as a point cloud, a set of structured or unstructured points. In a 3D representation, the points can be the x, y, and z coordinates of the data. Most likely, the data from scanning an object is unstructured where no connectivity is received. This makes this sort of data computationally heavy and hard to reconstruct.

Over the years, quite a few algorithms for surface reconstruction have been developed using different methods. One popular method is to make triangulated surfaces using Voronoi diagrams and Delaunay triangulation. A Voronoi diagram of a plane divides the plane into polygonal regions where every point has its region. The size of every region is all points in the plane that are closer to the associated point than any other point [30]. Delaunay triangulation constructs triangles from points in the plane in which the triangles are as equiangular as possible using circumcircles [31].

The α-shape algorithm [32, 33] uses Voronoi diagrams and Delaunay triangulation to construct a family of α-shapes to get the shape of an object. The Crust algorithm [34] uses both Voronoi diagrams and Delaunay triangulation but also the medial axis to reconstruct the surface. Power Crust [35] is an improved version of the Crust algorithm, however, when the sampling is too dense the time it takes to run the algorithm is very high [30]. Another algorithm is Cocone
[36] which is a simplification of the Crust algorithm. The Tight Cocone [37] is a watertight version of the Cocone algorithm which fills up the holes left behind from another surface reconstruction algorithm.

This project aims to perform MWI on breast phantoms of both known and unknown geometry using the provided microwave applicator and antenna with feedback to the user. To achieve this, the breast phantom will be scanned from several angles using a SAY equipped with a laser distance sensor and reconstructed in 3D. A Graphical User Interface

© ProjectBase 7.0 Baseline Management AB, 2018 | 2 | 2023-10-26

2.1 State Of the Art | 2.1 State Of the Art

(GUI) will be developed to provide feedback and control. The microwave applicator will be positioned accurately below the phantom and the antenna will be positioned using the same SAY.

### 2.1 State Of the Art

As mentioned in the previous section, MDU researchers proposed a groundbreaking system designed for operation in the open air, eliminating the need for coupling liquids. They determined that employing excitation devices can avoid issues associated with surface waves [22]. They later designed another microwave applicator, which transmitted energy directly into the breast instead of air [23]. In 2022, MDU students worked on a project involving an applicator and an antenna. They employed a laser distance sensor and a SAY to reconstruct the surface of a breast phantom. The antenna was positioned on the Yumi arm alongside a laser-based distance sensor and a stepper motor-driven actuator to position and relocate the microwave applicator under the breast. The surface reconstruction accuracy in this project fell short of the desired level with a mean error of 17.5 mm, which made it difficult to evaluate the methods used [24].

In the research conducted by Kurrant et al. [38], they successfully generated breast surface estimates by employing various sensing modalities. The system used in this research consists of a microwave measurement tank filled with a coupling medium, a laser, an electromagnetic sensor attached to an arm, an adjustable antenna, and an external camera for the breast’s position and antenna placement. The arm moves vertically within the microwave measurement tank at a specified distance from the breast phantom to capture its profile using laser samples. The surface model is built by creating evenly distributed contours along the object’s height using data from estimated profiles. The separation between these contours is determined by calculating the difference in height, and the extent along the z-axis remains constant for all profiles. These calculations are then used to produce the object’s surface by equilateral triangles. Three breast models were tested with the best result at 0.90 mm and the worst result at 1.18 mm of distance error mean, with 20 profiles which is the protocol at the University of Calgary. The process of scanning takes less than 30 minutes per breast depending on the amount of the profiles.

Pallone et al. [39], created an innovative laser scanning system with the ability to precisely reconstruct a surface representation of breast-shaped phantoms. This scanning system employs two laser line generators and a compact Charged-coupled device (CCD) camera is arranged concentrically on a rotating gantry positioned around the microwave imaging tank making it possible to rotate around the centre of the imaging tank where the breast phantom is positioned. This article outlines the design and functioning of the laser scanner and evaluates the effectiveness of several calibration methods such as analytical ray tracing and piecewise linear, locally weighted mean, polynomial, and thin-plate-spline image registration. In this research, the calibration through image registration consistently achieved mean surface errors of under 0.5 mm depending on the geometric complexity of the scanned object. In comparison to the ray tracing strategy, all the image registration methods performed better. However, the authors determined the global polynomial methods as the most effective in striking a balance between average surface error and scanner reliability. The laser scanning system offers a rapid and precise means of capturing 3D surfaces in the typical watery surroundings encountered during microwave breast imaging. Optical distortions caused by the imaging tank and coupling bath reduced the efficiency of the ray tracing method. Nevertheless, calibration using image registration techniques consistently generated scans with sub-millimetre precision.

In pursuit of rapid 3D surface reconstruction from scattered point clouds, Wang [40] introduces an innovative algorithm for laser imaging radar. This algorithm aims to reconstruct a detailed 3D depth surface using both depth and image data. The process begins with the division of 3D space into smaller units called voxels and outliers are then identified using point histogram features. Next, Gaussian process regression is applied to create a surface resembling a Gaussian distribution. Finally, they combined high-resolution grey data with 3D interpolation points, using Markov random fields for this purpose, where the result is a dense 3D depth surface. Experimental results confirm significant improvements in reconstruction accuracy and robustness. The proposed algorithm performs better compared to other algorithms such as Joint Bilateral Upsampling (JBU), Anisotropic Total General Variation (ATGV) and Markov Random Field model (MRF). While both the JBU and ATGV algorithms demonstrate good reconstruction capabilities, their complexity remains too large for practical engineering applications.

To improve Diffuse optical tomography, Morris et al. [41] developed a breast shape acquisition system in their research. This Structured Light Imaging system (SLI) which uses two cameras and a central projector, acquires accurate breast shape information in a way that is similar to mammography. The system adjusts the intensity of the lighting to accommodate different skin tones and minimizes issues caused by reflections. The SLI system is securely positioned on a stationary compression plate, in front of the patient’s breast. The fundamental idea behind the SLI system is to obtain 3D surface information by analyzing multiple 2D images of predefined distorted patterns. The proposed SLI system was designed to offer a compact, cost-effective solution especially for the challenges posed by low-light conditions and the limited space requirements of mammography compression settings. The system achieves sub-millimeter resolution, with a mean surface error of 0.26 mm.

© ProjectBase 7.0 Baseline Management AB, 2018 | 3 | 2023-10-26

### 3 Purpose

The purpose of this project is to further advance the research of the project owners by designing a system that can perform a non-contacting and non-ionizing screening for breast cancer using MWI. Subsequently, the project will give the owners of the project a platform on which to advance the research even further.

### 4 Goal

The goal of the parent project is to design a system which can conduct automatic microwave measurements to detect breast cancer. This iteration of the project will focus on designing a prototype system which can make automated microwave measurements on a simple breast phantom first with known, then with unknown geometrics.

### 5 Scope

The scope of the project is described by a Work Breakdown Structure (WBS), see Section 9.1.

### 6 Limitations

To create realistic expectations among the different stakeholders, the project introduces the following limitations:
- The project is constrained to 19 weeks.
- The project is limited to a budget of 20 000 SEK.
- The project will not perform testing on human subjects.
- The finished product lacks safety certifications.
- The finished product lacks energy saving certifications.
- The finished product lacks EMI/EMC certificate.
- The team will not produce a product meant for commercial use and only create a proof of concept.
- The end product will not encompass an automated process.
- The surface reconstruction software will not produce an exact replica of the scanned object.
- The finished product will not be designed with patient practicality in mind.
- The SAY control programming language is limited to RAPID.
- The number of licenses for Robot Studio are limited and can only be used on the school computers.
- The software is not guaranteed to be free of bugs.
- Software to process microwaves will not be produced.

### 7 Requirements

The requirements for the product can be categorized into hardware and software requirements. All these are considered soft requirements, meaning that they are not absolute.

### 7.1 Hardware product requirements

The requirements for the hardware can further be divided into functional and non-functional requirements.

### 7.1.1 Functional requirements

The functional hardware requirements outline the specific hardware-related tasks and operations that the product is expected to perform.
- The microwave transmitter position shall be adjustable in height to accommodate different objects under study sizes.
- Laser distance measurement sensor shall only be active when stationary and distance measurement mode is active.
- The laser shall be able to turn OFF manually in a critical situation.
- The user frame origin of the SAY and the base centre of all objects under study shall coincide without needing realigning.
© ProjectBase 7.0 Baseline Management AB, 2018 | 4 | 2023-10-26

7.2 Software product requirements | 7.2 Software product requirements

### 7.1.2 Non-functional requirements

The non-functional hardware requirements describe the hardware-related specifications of the product in detail.
- The SAY shall have pose repeatability within 1 mm.
- The microwave receiver of the SAY shall be able to reach all points on the surface from 10 degrees to 60 degrees in elevation angle of the object under study, perpendicular to the surface, without colliding with anything.
- The distance between the microwave transmitter and the object under study shall be 1 mm.

### 7.2 Software product requirements

The software requirements can also be divided into functional and non-functional requirements.

### 7.2.1 Functional requirements

The functional requirements for the software describe the functions that the product must do.
- The SAY shall avoid collisions with the environment.
- The SAY shall not damage the mounted microwave receiver and laser distance sensor.
- The 3D reconstruction algorithm shall digitally reconstruct the object under study with the provided scanning data.
- The movement of the SAY shall be synchronized with the microwave measurement equipment to perform automated measurements.
- The system shall be able to generate visual images from the laser data for the user.
- The user shall be able to control the robot arm manually.
- The SAY shall be able to move to a specific position given by the user.

### 7.2.2 Non-functional requirements

The non-functional requirements for the software relate to the technical specifications of the product in a detailed way.
- The SAY shall be controllable through software in all directions with a step size smaller than 1mm.
- The system shall be able to produce a point cloud consisting of 120 points in less than 10 minutes.

### 7.3 Project requirements

The requirements of the project can be specified as follows:
- The development phase of the project shall be finished on the 14th of December 2023.
- The project shall be finished on the 11th of January 2024.
- All documents, code, and equipment shall be stored and returned according to the specified handover plan, see Section 17.

### 7.4 Prerequisites

Prerequisites that need to be provided by the project owners are the SAY collaborative robot and the microwave imaging system, which includes the signal analyzer, antennas, cables and any relevant software.

### 8 Situational analysis and stakeholders

The following section gives an overview of the current situation by presenting a SWOT analysis. Additionally, the different stakeholders of the project are presented.

© ProjectBase 7.0 Baseline Management AB, 2018 | 5 | 2023-10-26

8.1 SWOT-analysis | | 8.1 SWOT-analysis

### 8.1 SWOT-analysis

The following SWOT analysis gives an overview of internal and external factors that can influence the execution and result of the project.
Strengths:
- Agile team which can adapt quickly to changes.
- Broad skill set among the team members, with backgrounds within both robotics- and network engineering.
- Stakeholders have a lot of knowledge of the subject.
Weaknesses:
- Limited funding.
- Lack of experience operating and controlling autonomous robots.
- Limited time frame.
- Limited knowledge of microwave imaging.
Opportunities:
- Collaboration with researchers.
- Be a part of creating a novel system.
- Testing new technology.
- Possibility to be part of publishing a paper if the measurements are successful.
- This project can continue as a master thesis.
Threats:
- Acquired equipment being defective upon arrival.
- ABB SAY robotic arm relies on technology from ABB. Meaning if something goes wrong with the robotic arm, the progress of the project may slow down.
- Equipment can be damaged or lost for some reason including burned or stolen. It slows down the progress of the project.
Conclusions:
- Need to ensure the quality and functionality of equipment early to quickly adapt and find other solutions.
- Be careful with how we store the equipment and lock away the items that could risk being stolen.
- Keep in contact with ABB so they can provide assistance if the equipment needs to be calibrated or fixed in some way.
- Planning is important to use the time in a good way.
- By collaborating with researchers and stakeholders, their expertise and resources can be used to overcome our limited knowledge of microwave imaging.

### 8.2 Stakeholder mapping

- Internal Stakeholders: Nikola Petrovic and Cristoph Salomon are the stakeholders in this project.
- Investors: ABB provided the SAY.
- Partners: Mälardalen University.
- Customers: Hospital employees will operate this product once it is fully developed.
- Competitors: Umbria Bioengineering Technologies have developed and patented Mammowave which uses microwaves for breast cancer detection [42]. Wavelia is another competitor that also uses microwaves for breast cancer detection [43].

### 9 Planning

This section contains the planning of the project, which includes a WBS and Gantt chart to visualise what needs to be done and when it should be finished.

© ProjectBase 7.0 Baseline Management AB, 2018 | 6 | 2023-10-26

9.1 Work breakdown structure | 9.1 Work breakdown structure

### 9.1 Work breakdown structure

This section contains a WBS diagram for the whole project, including both software and hardware. The root of the WBS is the project itself. There are two main components that represent the broad stages of the project. Further, there are several work packages representing the breakdown of what has to be done to achieve each component. There are also deliverables, which are the tangible or intangible products or services that are developed during the project. Deliverables can therefore be handed over in digital or physical format. At the bottom of the WBS hierarchy are the tasks, which describe all the work necessary to complete each deliverable.
ID | Type | Activity
1 | Root | Microwave Imaging for Breast Cancer Detection: A Non-Contacting Approach
1.1 | Component | Perform automated microwave measurements on a simple breast phantom with known geometrics
1.1.1 | Work package | Robot arm
1.1.1.1 | Deliverable | Control of the robot arm
1.1.1.1.1 | Task | Test range of motion manually
1.1.1.1.2 | Task | Socket connection/communication
1.1.1.1.3 | Task | Get familiar with Robot Studio
1.1.1.1.4 | Task | Path planning
1.1.1.1.5 | Task | Collision avoidance
1.1.1.1.6 | Task | Transformation between coordinate systems
1.1.1.1.7 | Task | Arm angle
1.1.1.1.8 | Task | Simulations
1.1.1.1.9 | Task | Save positions
1.1.1.1.10 | Task | Move manually
1.1.1.1.11 | Task | Calibration
1.1.1.2 | Deliverable | Testing
1.1.1.2.1 | Task | Test outside of frame
1.1.1.2.2 | Task | Test inside of frame
1.1.1.3 | Deliverable | Documentation
1.1.2 | Work package | Platform
1.1.2.1 | Deliverable | Set up the new frame
1.1.2.1.1 | Task | Mount all the boards and aluminum profile
© ProjectBase 7.0 Baseline Management AB, 2018 | 7 | 2023-10-26

9.1 Work breakdown structure | 9.1 Work breakdown structure
ID | Type | Activity
1.1.2.1.2 | Task | Adding features for robustness
1.1.2.1.3 | Task | Safety features
1.1.2.1.4 | Task | Equipment placement
1.1.2.1.5 | Task | Cable management
1.1.2.1.6 | Task | Hole for breast phantom
1.1.2.4 | Deliverable | Documentation
1.1.3 | Work package | Sender platform
1.1.3.1 | Deliverable | New platform
1.1.3.1.1 | Task | Evaluation and comparison of the old platform
1.1.3.1.2 | Task | Designing
1.1.3.1.3 | Task | 3D-Printing
1.1.3.1.4 | Task | Positioning
1.1.3.1.5 | Task | Get dimensions of transmitter
1.1.3.1.6 | Task | 3D-Print transmitter for testing
1.1.3.2 | Deliverable | Automated control
1.1.3.2.1 | Task | Moving functionality
1.1.3.2.2 | Task | Motor control
1.1.3.2.3 | Task | Testing
1.1.3.3 | Deliverable | Documentation
1.1.4 | Work package | Robot tool/end-effector
1.1.4.1 | Deliverable | New tool
1.1.4.1.1 | Task | Evaluation and comparison of last iterations tool
1.1.4.1.2 | Task | Fit laser and antenna
1.1.4.1.3 | Task | Designing
1.1.4.1.4 | Task | 3D-Printing
1.1.4.1.5 | Task | Mounting
1.1.4.1.6 | Task | Get dimensions of the microwave antenna
© ProjectBase 7.0 Baseline Management AB, 2018 | 8 | 2023-10-26

9.1 Work breakdown structure | 9.1 Work breakdown structure
ID | Type | Activity
1.1.4.1.7 | Task | Print antenna for testing
1.1.4.2 | Deliverable | Documentation
1.1.5 | Work package | Breast phantoms
1.1.5.1 | Deliverable | Old phantoms
1.1.5.1.1 | Task | Obtain the available phantoms
1.1.5.2 | Deliverable | New phantoms
1.1.5.2.1 | Task | Get the required dimensions
1.1.5.2.2 | Task | 3D-print prototypes
1.1.5.2.3 | Task | 3D-print using printer in Eskilstuna
1.1.5.3 | Deliverable | Holder for phantoms
1.1.5.3.1 | Task | Design
1.1.5.3.2 | Task | 3D-printing
1.1.5.3 | Deliverable | Documentation
1.1.6 | Work package | Central control system
1.1.6.1 | Deliverable | New control unit
1.1.6.1.1 | Task | Evaluation of Beagle Board vs. Raspberry Pi
1.1.6.1.2 | Task | Possibly transition to Raspberry Pi
1.1.6.2 | Deliverable | Connection management
1.1.6.2.1 | Task | Sensors and actuators
1.1.6.2.2 | Task | Robot arm
1.1.6.3 | Deliverable | Documentation
1.1.7 | Work package | Network
1.1.7.1 | Deliverable | Connection between all subsystems
1.1.7.1.1 | Task | Robot controller and robot arm
1.1.7.1.2 | Task | PC
1.1.7.2 | Deliverable | Documentation
© ProjectBase 7.0 Baseline Management AB, 2018 | 9 | 2023-10-26

9.1 Work breakdown structure | 9.1 Work breakdown structure
ID | Type | Activity
1.1.8 | Work package | GUI
1.1.8.1 | Deliverable | Interface for control and displaying results
1.1.8.1.1 | Task | Emergency stop button
1.1.8.1.2 | Task | Buttons for control of robot arm in different coordinate systems
1.1.8.1.3 | Task | Buttons for control of sender platform
1.1.8.1.4 | Task | Buttons for control of laser measurements
1.1.8.1.5 | Task | Buttons for control of the microwave measurements
1.1.8.1.6 | Task | Visualisation of the measurements
1.1.8.1.7 | Task | Visualisation of results
1.1.8.1.8 | Task | Controls with manual control similar to the joystick on the controller
1.1.8.2 | Deliverable | Documentation
1.2 | Component | Perform automated microwave measurements on a simple breast phantom with unknown geometrics
1.2.1 | Work package | Laser
1.2.1.1 | Deliverable | 3D-Scanning
1.2.1.1.1 | Task | Distance measurements
1.2.1.1.2 | Task | Turn on/off
1.2.1.1.3 | Task | Distance in mm
1.2.1.1.4 | Task | Moving average
1.2.1.1.5 | Task | Get general information from sensor
1.2.1.1.6 | Task | Save sensor data
1.2.1.2 | Deliverable | Safety features
1.2.1.2.1 | Task | Physical emergency stop button
1.2.1.3 | Deliverable | Testing
1.2.1.3.1 | Task | Box/cover to make it dark for measurements
1.2.1.3.2 | Task | Test range
© ProjectBase 7.0 Baseline Management AB, 2018 | 10 | 2023-10-26

9.1 Work breakdown structure | 9.1 Work breakdown structure
ID | Type | Activity
1.2.1.4 | Deliverable | Calibration
1.2.1.4.1 | Task | 3D-Print calibration holder
1.2.1.5 | Deliverable | Documentation
1.2.2 | Work package | Microwave measurements
1.2.2.1 | Deliverable | Get familiar with the equipment
1.2.2.1.1 | Task | Obtain the equipment
1.2.2.1.2 | Task | Get introduction from supervisors
1.2.2.2 | Deliverable | Functionality for the measurements
1.2.2.2.1 | Task | User can choose area
1.2.2.2.2 | Task | Scanning points based on given positions
1.2.2.2.3 | Task | Move transmitter and receiver to defined positions
1.2.2.2.4 | Task | Perform measurements
1.2.2.2.5 | Task | Save data
1.2.2.3 | Deliverable | Documentation
1.2.3 | Work package | Surface reconstruction
1.2.3.1 | Deliverable | Implement algorithms
1.2.3.1.1 | Task | Evaluation of the algorithms used during the last iteration
1.2.3.1.2 | Task | Research algorithms
1.2.3.1.3 | Task | Load saved model
1.2.3.1.4 | Task | Save created model
1.2.3.1.5 | Task | Display model
1.2.3.2 | Deliverable | Evaluate algorithms
1.2.3.2.1 | Task | Metrics for evaluation
1.2.3.2.2 | Task | Visualisation of result
1.2.3.3 | Deliverable | Documentation
© ProjectBase 7.0 Baseline Management AB, 2018 | 11 | 2023-10-26

9.2 Schedule | 9.2 Schedule

### 9.2 Schedule

Following is a Gantt chart for the whole project, including both software and hardware. The schedule is based on the WBS, where the work packages and their deliverables have been scheduled. During the time frames for each work package the tasks will be scheduled using a Kanban board in Microsoft Teams Planner. This method is further explained in Section 12.1. This schedule is an estimation and it can change during the execution, many of the work packages will be started earlier and can be performed in parallel as long as the resources allow for it.

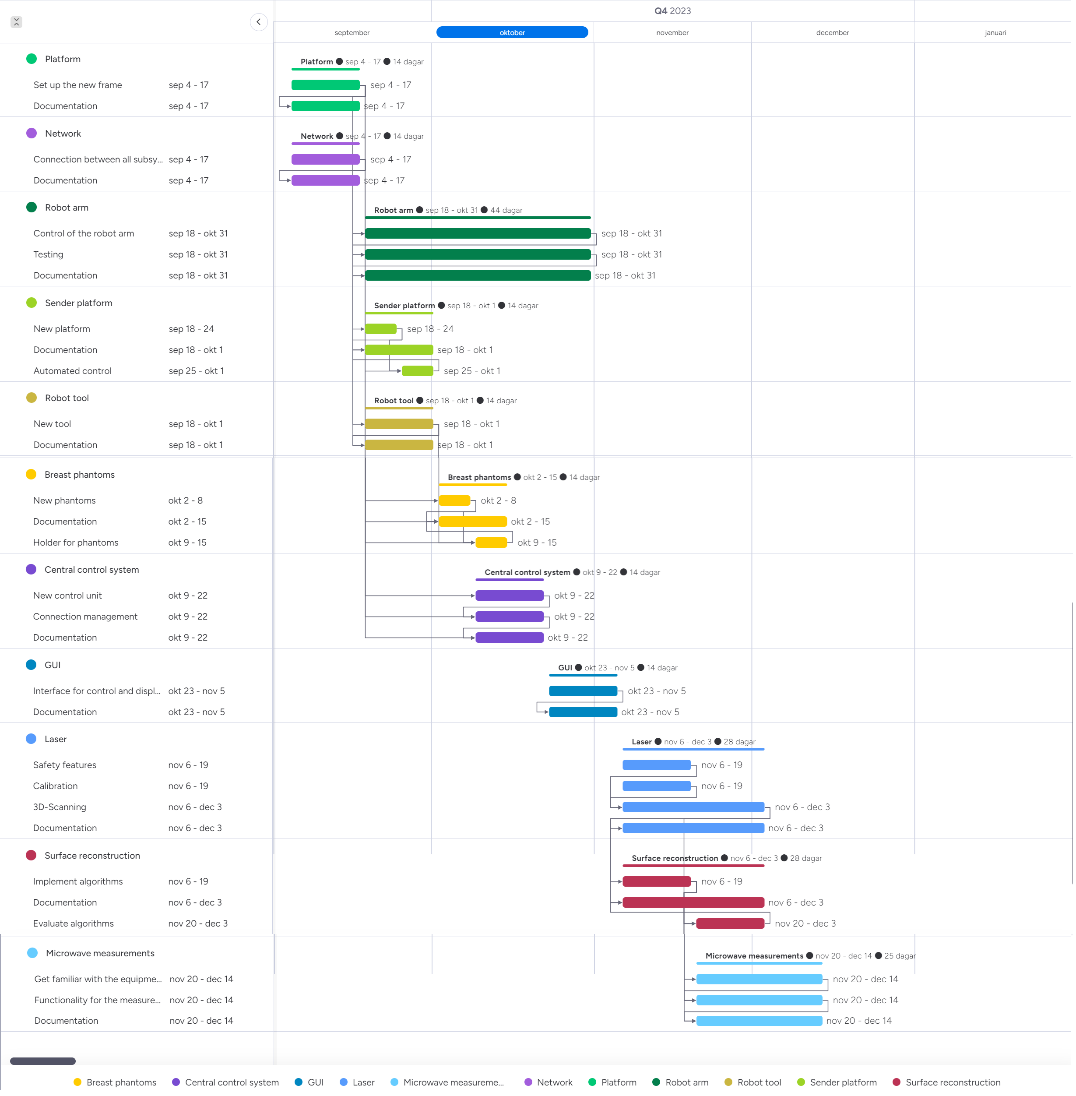
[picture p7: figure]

Figure 1: Gantt chart displaying an approximation of the timeline for the project.

### 10 Staffing

The staffing of the project outlines the responsibilities for each role as well as assigns a role to each member of the team.

### 10.1 Roles, responsibilities and authorities

- Hardware Team Leader: Oversees the hardware team, coordinates with the software team lead and is responsible for hardware-related tasks.
© ProjectBase 7.0 Baseline Management AB, 2018 | 12 | 2023-10-26

10.2 Staffing plan | 10.2 Staffing plan
- Hardware Developer: Produces and designs hardware components, tests the hardware and deals with issues regarding the hardware.
- Software Team Leader: Oversees the software team, coordinates with the hardware team lead and is responsible for software-related tasks.
- Software Developer: Develops and tests software and deals with issues regarding the software.

### 10.2 Staffing plan

Our staffing plan assigns roles to each member of our project team as follows:
- Dennis Landré - Hardware Team Lead.
- Ihsan Haidari - Hardware Developer.
- Märta Krönström - Software Team Lead.
- Filip Lindhe - Software Developer.
- Jiantao Shen - Software Developer.
- Joel Josefsson - Software Developer.
- Samuel Wågbrant - Software Developer.
Each individual was chosen for their role based on their skills, experience, and interest in the project. Regular meetings will be held to ensure that everyone is on track and to address any concerns that may arise.

### 11 Project budget

This is an estimation of the project budget, during the process it will develop and products will be added. As the stakeholders of the project already provided most of the necessary hardware equipment the estimation is well within the limit of 20 000 SEK.

Product | Cost (SEK)
Raspberry Pi 4B (8GB) | 1400
Raspberry Pi power supply | 150
Mounting hardware | 1000
Linear actuator | 2000
Aluminium profile strut and connecting components | 650

### 12 Development Plan

The development plan provides information about the project, such as our technical approach, methodologies we shall employ and each team member’s roles and responsibilities. The plan is designed to make the process of integrating new members easier at any stage of the project.

### 12.1 Development Methodology

Our team follows a modified version of the linear development methodology model, waterfall. With the waterfall model, each development phase follows a sequential pattern where the following phases can not be started before the previous phase is completed [44]. The waterfall model relies on requirements being defined before any development starts to establish the expected outcome following the development phase’s end, see Figure 2. That which differs in our methodology from the traditional waterfall model is that testing will occur after each work package is completed to ensure that potential bugs and misbehaviour of the system are identified as early as possible. To maintain high quality, testing and documentation will occur continuously in each phase.

© ProjectBase 7.0 Baseline Management AB, 2018 | 13 | 2023-10-26

12.2 Team Structure and Roles | 12.2 Team Structure and Roles

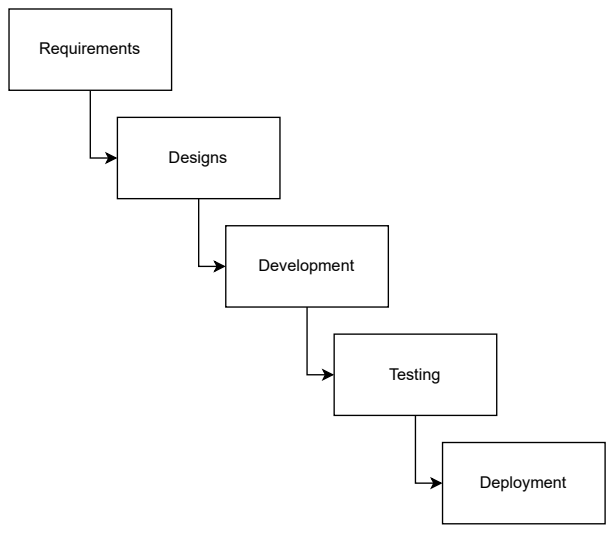
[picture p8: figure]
Requirements; Designs; Deployment; Development; Testing

Figure 2: Flowchart of the different stages in the waterfall model

For scheduling and distribution of tasks, the team will use a kanban board [45]. A kanban board helps the team visualise the workflow of the project by using a four-state system, where each task will be in one of four states, see Figure 3. Each individual task will be assigned to a project member or a group of project members, by the team leads, depending on the scope of the task. This process is done through the Task Manager found in Microsoft Teams [46]. When a task has been assigned it is transferred from the To Do stage to the Work in Progress stage where it remains until the task is developed and ready for testing. During the testing stage, it will either pass meaning the task is moved to the Completed state, or fail meaning the task will move back to the Work in Progress state. This system also helps to give an overview of the completed tasks as they are saved in Teams.

Figure 3: Flowchart of the different states individual tasks assume during development when using a kanban board

### 12.2 Team Structure and Roles

Our team is comprised of the following roles:
- Hardware Team Leader Responsible for the hardware development process and responsible for ensuring that hardware-related requirements are fulfilled. Additional responsibilities are stated in section 10.1.
- Software Team Leader Responsible for the software development process and responsible for ensuring that software-related requirements are fulfilled. Additional responsibilities are stated in section 10.1.
- Hardware Developer Responsibilities stated in section 10.1
- Software Developer Responsibilities stated in section 10.1

### 12.3 Tools, Technologies, and Systems

We leverage the following tools, technologies, and systems in our project:
- Software Development Tools:
– Python 3.10.11: Is used as the main programming language in this project. The reasoning behind using this specific version of Python is that the project will use a library called Open3D which is compatible with Python versions < 3.11. The features that will use Python are surface reconstruction, a GUI, controlling the measurements of the optoNCDT 1402-100 laser sensor, managing the positioning of the antenna, and controlling the movement of the sender robot. If extra communication code is needed, it will be written using Python. Python can be downloaded from [47].
© ProjectBase 7.0 Baseline Management AB, 2018 | 14 | 2023-10-26

12.4 Coding Standards and Guidelines | 12.4 Coding Standards and Guidelines

– Visual studio code: Is used as the main Integrated Development Environment (IDE) for writing Python code. It can be downloaded here [48].
– ABB Rapid: Is used as the main programming language on the ABB SAY to control the arm movement and to host a TCP socket server.
– RobotStudio: Is used as a way to simulate and control the robot arm and can be downloaded from [49].
- Project Management Tools:
– Microsoft Teams: Is utilised for planning, dividing tasks, storage of material, common calendar, and documentation of the project. It can be downloaded from [46].
- Documentation and Research tools:
– Overleaf: Is used as the text editor when writing reports using Latex [50].
– Reasearchrabbit and Zotero are used as a way to store and share the papers and reports that we read and use as references in the project. Researchrabbit can be found at [51] and Zotero at [52].
- Communication Tools: For effective communication, within the group and towards the supervisors we use Microsoft Teams, which can be downloaded from [46].
- Hardware Tools and Software:
– SolidWorks: Is used for 3D modelling, and can be downloaded from [53].
– PrusaSlicer: G-code is generated using the PrusaSlicer software that can be downloaded from [54].
– Original Prusa I3 MK3 3D-printer: It features a removable build plate, an auto-levelling sensor, a Bowden extruder, a workspace volume of 25 x 21 x 21 cm and can only use 1.75 mm PLA/ABS filament [55].
- Operating Systems:
– Microsoft Windows 10 Education, version 22H2: Is primarily used on the team’s PCs.
– Windows CE: Is used on the Flex pendant for the SAY [56].
– Raspberry Pi OS (64-bit) Debian version 11 (Bullseye): Is used on the Raspberry Pi 4B [57].
- Hardware:
– Single-Arm YuMi: Is a collaborative robot with a maximum reach of 0.559m and a payload of 0.5kg [58]. – optoNCDT 1402-100: Is an intelligent laser optical displacement measurement sensor with an integrated signal processor and a measuring range of 100 mm [59].
– Raspberry Pi 4: Is a tiny desktop computer that will run all the finished code.

### 12.4 Coding Standards and Guidelines

To ensure that the code written for this project achieves high quality, readability, and consistency the Black coding standard for the programming language Python is used [60]. Black follows the PEP 8 coding standard for Python and can be considered a subset of PEP 8. Black allows us to integrate it with GitHub for automatic formatting of the code according to the coding standard. If any RAPID code needs to be written we will use ABB Rapid software development guidelines seen here [61].

### 12.5 Version Control

We utilise Git to manage changes to our project files and maintain different versions. We use GitHub as a place to store and manage this project’s version history. More information on GitHub can be seen here [62]. The link to our repository for this project can be seen here [63].

### 12.6 Testing and Quality Assurance

Unit testing will be done at the end of each task. And it will be done by the developer who is in charge of the task. Testing and bugs will be recorded according to the testing standards in Section 16. Testing of the entire system will be conducted during the testing stage. The reason for continuous testing is to make sure everything works as intended and to catch any issues early.

### 12.7 Integration and Deployment

Integration and deployment of the code will be done after each work package is fully completed, including testing, by merging the branch of the work package into the main branch of the repository.

© ProjectBase 7.0 Baseline Management AB, 2018 | 15 | 2023-10-26

### 13 Communication plan

The communication plan aims to guide the team members on how communication will be handled throughout the project. Communication throughout the project will primarily be done through physical meetings and Microsoft Teams [46]. Project tasks will be maintained and distributed through Microsoft Teams. This strategic document lays out various aspects of communication, such as the type of information that needs to be distributed, the audience for each type of information, the timing or frequency of communication, and the mediums or channels for transmitting the information.
- Item/Event: This refers to the item or event of the communication. For example, daily meetings, stakeholder meetings, or information sharing of issues.
- Why (Purpose): This refers to the reason behind the communication. For example, project updates to inform stakeholders about progress, and task assignments may be needed to guide the developers.
- Who (Target Audience): This determines who needs to receive specific information. This could include project members such as the hardware and software developers, hardware and software team leaders, and stakeholders.
- When (Timing): This indicates when and how frequently the communication should occur. This could be daily, weekly, biweekly, monthly, or at specific project milestones, depending on the nature of the information.
- How (Communication Channels): This determines how the information will be delivered. Communication methods include communication software, direct communication, meetings, and project management software.
- Responsible: This identifies who is responsible for ensuring the communication happens. This can vary depending on the type of information and the target audience.
Item/Event | Why | Who | When | How | Responsible
Daily meeting | Status of project team members and plan the coming day | Project members | Daily | Physical meetings | Hardware and Software Leads
Weekly meeting | Discuss problems in-depth, plan coming stakeholder meeting | Project members | Weekly | Physical meetings | Hardware and Software Leads
Stakeholder meeting | Keep stakeholders updated, discuss issues and questions | Project members and stakeholders | Weekly | Physical meetings | Hardware and Software Leads
SW Task Assignments | For developers to know their assignment | SW Developer | As needed | Project Management Software | Software Lead
HW Task Assignments | For developers to know their assignment | HW Developer | As needed | Project Management Software | Hardware Lead
Minor issue | If project member needs help with a minor issue | Project members | As needed | Contact team lead or developer with right knowledge | Project members
Major issue | If project member needs help with a major issue | Project members | As needed | Discuss at next daily or weekly meeting | Project members
Information sharing | Information that needs to be shared with the team | Project members | As needed | Microsoft Teams | Project members
Stakeholder forum | If questions for stakeholders arise that can be answered without meeting | Project members and stakeholders | As needed | Microsoft Teams | Project members

### 14 Risk analysis and response planning

In this section, we describe our risk analysis and response planning as part of our project. The risk score is calculated by multiplying the probability and impact score of a risk, where the probability is ranked from 1, very unlikely to 5, very likely and the impact score is ranked from 1, minimal to 5, critical.
The risk score thresholds are interpreted as follows:
- 1-5: Low priority risks. These are monitored but may not require immediate action.
- 6-10: Medium priority risks. These require a mitigation plan and should be addressed as resources allow.
© ProjectBase 7.0 Baseline Management AB, 2018 | 16 | 2023-10-26

- 11-15: High priority risks. These require a detailed mitigation plan, and resources should be allocated to address these risks immediately.
- 16-25: Critical risks. These must be addressed immediately with a detailed and efficient mitigation plan to avoid severe project disruption.
The table below outlines the identified risks, their evaluation, and planned responses:
Risk | Probability(1 to 5) | Impact(1 to 5) | Risk(P*I) | Risk Response
Critical team member leaves during the project | 2 | 5 | 10 | Develop contingency plan, cross-train team members
Scope creep leading to project delay | 1 | 4 | 4 | Regular scope review, robust change management process
Technology becomes obsolete | 1 | 4 | 4 | Regularly update technological skill sets, maintain flexibility in tech stack
Software bugs detected after deployment | 3 | 5 | 15 | Rigorous testing process, allocate resources for post-deployment bug fixes
Unexpected budget cuts | 1 | 3 | 3 | Prepare a flexible budget that can accommodate cuts, regular financial reviews
SAY positioning not repeatable enough | 3 | 5 | 15 | Test the repeatability at an early stage and prepare contacts with ABB
One measurement sensor is not good enough for object reconstruction | 3 | 4 | 12 | Test the accuracy at an early stage and research alternative solutions
Hardware malfunctions requiring spare parts or replacements | 2 | 4 | 8 | Test hardware at an early stage to identify problems, prepare contacts with suppliers
Unexpected delay occurs for ordered components | 2 | 5 | 10 | Develop contingency plans, identify alternative components and suppliers
Unexpected delay in a dependent work package is causing a delay in the subsequent work package | 3 | 4 | 12 | Reassess the schedule and consider reallocating resources to speed up the delayed work package or the subsequent work package.

### 15 Documentation plan

The documentation plan outlines the fundamental guidelines for recording and preserving important information throughout the project’s duration. This plan provides details about what should be documented, how to document, when to document, the responsible party, and where to document.

### 15.1 What to Document

- Code comments shall be written in all code.
- Meeting notes for group meetings.
- Meeting notes for supervision meetings.
- User manuals shall be documented to make sure everyone can operate the system, run any code, and test any equipment.
© ProjectBase 7.0 Baseline Management AB, 2018 | 17 | 2023-10-26

15.2 How to Document | | 15.2 How to Document

### 15.2 How to Document

- Code comments will be done in such a way that it is easy to understand how the code functions and it should be done according to the PEP-8 standard. See more information under section 12.4.
- Meeting notes will be written in such a way that they are easy to understand by everyone. If there is any ambiguity or questions regarding the notes than the members can ask the software team lead.
- User manuals will be documented in such a way that regardless of previous experience anyone should be able to follow the manual. Template for user manuals can be found in the GitHub repository under the folder Documents and is written using the text format Markdown.

### 15.3 When to Document

- Code comments will be continuously written to make sure that anyone can take over the development of the code.
- Meeting notes for group meetings will be documented when deemed necessary by the software team leader.
- Meeting notes for supervision meetings will be documented for each meeting within 24 hours.
- User manuals will be documented when the specific part related to the user manual is complete and functional.

### 15.4 Who is Responsible

Assign documentation duties to specific roles:
- Hardware Team Leader: Oversees and approves hardware-related documentation tasks.
- Software Team Leader: Oversees and approves software-related documentation tasks. Documents meetings.
- Hardware Developer: Creates and updates hardware-related documentation as assigned.
- Software Developer: Creates and updates software-related documentation as assigned.

### 15.5 Where to Store Documents

Documents will be stored in Microsoft Teams and on the GitHub repository. This is done to make sure it is easy to access by team members, stakeholders, and the examiner.

### 15.6 Document Review Process

Software- and hardware team leaders will review documents and task status weekly during the testing phase of the waterfall approach. When the system meets all requirements or enters its final week of testing phase, all team members will also review the documents to ensure they are understandable.

### 15.7 Training

Each team member is updated on the documentation process at the start of the project, or if a new team member is added they will be introduced to the documentation when they start.

### 16 Testing Plan

The testing plan documents the details of the testing strategy, tools and methodology that be used will use in the project. Its purpose is to help team members ensure that their work meets the requirements of the project.

### 16.1 Testing Methodology

During this project, manual testing is employed because an automated testing tool is expensive. Manual testing is both cost and time-efficient for smaller projects with limited budgets which benefits us. With manual testing, we are also able to create a large variety of tests not possible with automated tests.
Software testing methodology:
- Unit test: Our team performs unit tests to ensure there are no bugs or issues in certain parts of the system. Unit testing is when different parts of the system are tested individually. This methodology has been chosen due to its benefit that confirms every part of the system works as intended.
- Integration test: Our team performs integration tests to ensure that the GUI and the back-end can operate without issues. This methodology has been chosen to verify there are no issues between the GUI and the back-end systems.
- System test: Our team performs system tests to ensure the whole system, including hardware, operates without problem. This methodology has been chosen to verify that the final system works as intended.
© ProjectBase 7.0 Baseline Management AB, 2018 | 18 | 2023-10-26

16.2 Testing Team Structure and Roles | | 16.2 Testing Team Structure and Roles
- Acceptance test: Our team performs acceptance tests to ensure the whole system, including hardware, meets all requirements. This methodology has been chosen to verify our final system meets all functional and non-functional requirements.
Hardware testing methodology:
- Design validation: Our team follows the design validation to ensure the hardware meets the requirements. This methodology has been chosen due to its benefit that confirm 3D-printed model works correctly in the system.

### 16.2 Testing Team Structure and Roles

In our team, everyone is both testing team leader and test engineer in their own task:
- Testing Team Leader: Collaborates with both software and hardware teams to ensure the testing is completed on time.
- Test Engineer: Formulates and implements test case. Documents results and reports them in the team meetings.

### 16.3 Testing Tools, Technologies, and Systems

The testing tools that will be used in the testing process:
- Bug Tracking Tools: Microsoft Excel will be used to log bugs and track their status. Microsoft Excel can be downloaded from Microsoft Office 365 [64].
- Test Management Tools: Microsoft Excel will be used to document the testing process and results. It can be downloaded from Microsoft Office 365 [64].

### 16.4 Testing Standards and Guidelines

Create a test report template using Microsoft Excel to ensure consistency in the testing reports. The file is stored on GitHub [63].

### 16.5 Version Control for Test Artefacts

GitHub is the platform that will be used for managing modification of our test artefacts and storing different versions [63].

### 16.6 Bug Reporting and Tracking

A bug report file is created using Microsoft Excel. Every team member is responsible for reporting bugs in the file in GitHub [63].

### 16.7 Test Schedule

Unit testing should be performed after completing a part of the system. The system and acceptance testing will be performed after completing all main parts of the system.

### 16.8 Integration and Regression Testing

The integration and regression testing is performed once a function successfully passes the unit testing and merges with other functions.

### 17 Handover plan

The handover plan describes how the system will be delivered to the stakeholders at the end of the project. This includes who is responsible for what, what to deliver and how, and where the artefacts are located.

### 17.1 Handover Methodology

Our handover methodology includes:
- Inventory check to ensure all equipment received from the stakeholders and purchased equipment is returned to the stakeholders.
- All code and relevant files will be available via the public GitHub repository owned by MDU-C2 [63].
- Finalised documentation which includes; a final report for the project and documentation for use of the system, including hardware and software subsystems.
- Presentation for stakeholders, to ensure that the stakeholders are comfortable operating the presented deliverable. These steps have been chosen to ensure a comprehensive and efficient handover process.
© ProjectBase 7.0 Baseline Management AB, 2018 | 19 | 2023-10-26

17.2 Handover Team Structure and Roles | 17.2 Handover Team Structure and Roles

### 17.2 Handover Team Structure and Roles

Our handover team includes the following roles:
- Handover Team Leader: Schedules meetings with the stakeholders during the handover process. Responsible for handing over all deliverables.
- Handover Specialist: Ensures that the project owners are comfortable operating and understanding the project’s deliverables.

### 17.3 Handover Tools, Technologies, and Systems

The following tools are used in the handover process:
- Inventory Management Tools: We utilize Microsoft Excel to catalogue and track all equipment and project deliverables for handover, which can be downloaded from [64].
- Presentation Tools: If necessary, we use Microsoft PowerPoint to conduct presentations or demonstrations, which can be downloaded from [65].

### 17.4 Handover Schedule

Our handover schedule aligns with the overall project timeline. The handover is planned to align with the termination of the project. The handover schedule can be found in our project timeline, see section ??.

### 17.5 Documentation

All project documentation, including manuals, technical documentation and reports can be accessed by the project owners in the GitHub repository [63].

### 17.6 Presentation and Demonstration

Our team will ensure the project owners are familiar with the project’s operation and results with a presentation and demonstration preceding the handover.

### 17.7 Final Sign-off

Following a final meeting issued together with the project owners, the project owners will sign off, confirming the handover is complete.

### 17.8 Version Control for Handover Artefacts

We utilize Git to manage changes to our handover artefacts and maintain different versions. The repository used for this project can be found on GitHub [63]

### 17.9 Follow-up and Feedback

We value feedback from the project owners and have a process for follow-up. Follow-up questions from the project owners following the end of the project should first and foremost be directed to the hardware and software team leads of the project. Depending on the nature of the question, project owners may contact a developer directly if the project owners know that the developer is knowledgeable regarding the topic of the questions. This process ensures that all aspects of the handover are completed satisfactorily and addresses any potential concerns post-hand-over.
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

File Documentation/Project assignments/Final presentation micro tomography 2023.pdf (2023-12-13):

# Microwave imaging for breast cancer detection: A non-contacting approach

Ihsan Haidari
Joel Josefsson
Märta Krönström
Dennis Landré
Filip Lindhe
Jiantao Shen
Samuel Wågbrant
2023-12-14 | 1

# Motivation

- In Sweden breast cancer is the most common form of cancer among women
- Statistics for women in Sweden 2o21:
- 11 327 diagnosed
- Incidence of 218,9
- Prevalence was 122 166
- Number of deaths 1 326
- Since 1980 the number of cases has been increasing every year
- It is important to develop safe and comfortable methods for early detection

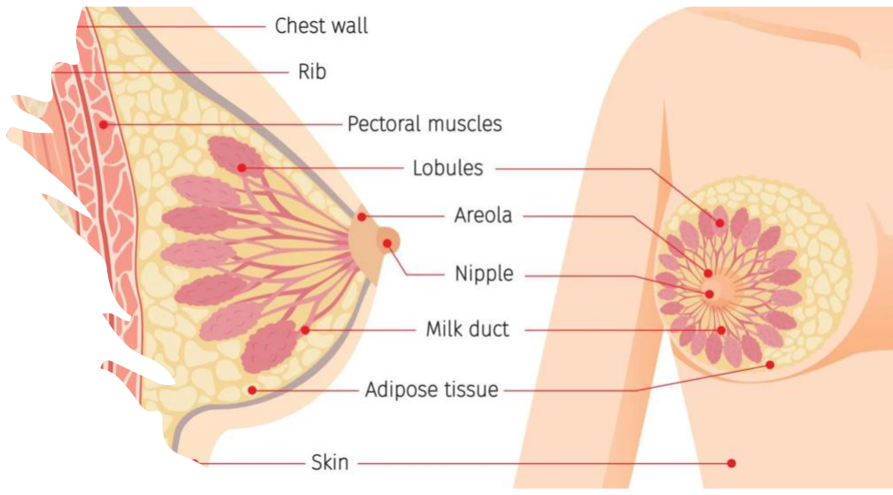
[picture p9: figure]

“CANCER I SIFFROR Populärvetenskapliga fakta om cancer 2023.” Available: https://www.socialstyrelsen.se/globalassets/sharepoint-dokument/dokument-webb/statistik/cancer-i-siffror-2023.pdf

# Breast cancer screening methods

X-ray mammography:
+ Primary method
+ High spatial resolution
+ Live imaging during biopsies
- Uncomfortable/painful breast compression
- Ionizing radiation
- Accuracy of result depending on radiologist experience
- Difficulty in distinguishing between tissues due to low contrast

# Microwave imaging (MWI)

+ Possible complement for mammography

+ Early detection
+ Non-contacting

+ Non-ionizing radiation
+ Fairly high contrast among different tissues
- No widely adopted systems for routine clinical use
- Many years of research + engineering
- Signal nature
- Computationally expensive

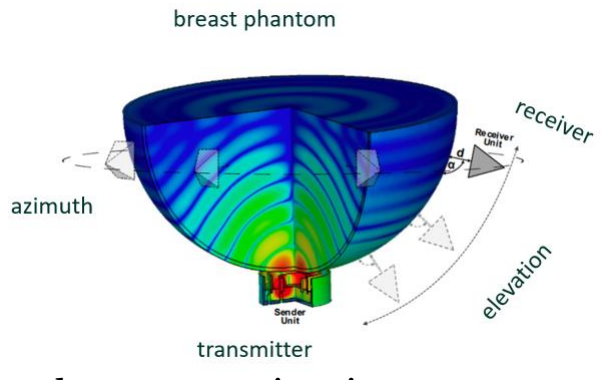
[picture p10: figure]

- Electromagnetic microwaves
- Microwaves penetrate, scatter, and reflect within the breast
- Scattered and reflected signals are received
- An internal breast image is constructed
- Dielectric properties of tumorous breast tissue differ from healthy tissue
Incident field | Scattered field 2023-12-14 | 4

# Resulting images

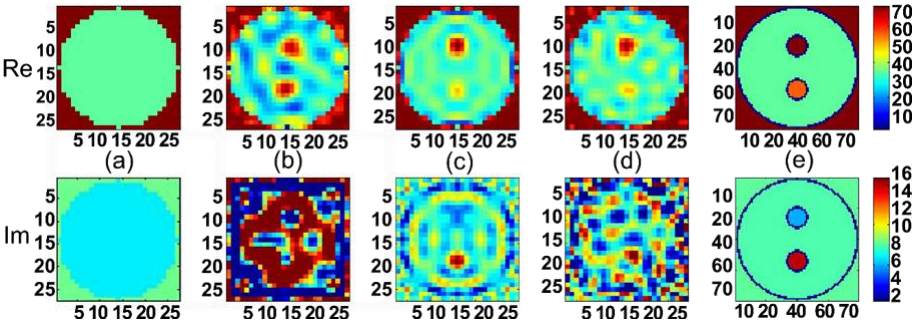
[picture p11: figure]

# Our project

- Microwave sensors for breast cancer detection
- Developed by researchers at MDU
- Goal: Automated measurements on a simple breast phantom with known/unknown geometry
- Problem: Need to find a way to move the microwave sensors automatically to various positions around the breast
- Laser-based surface estimation for unknown, irregular geometry
- Collaborative robot:
✓ Different from current approaches ✓ Safe
✓ Flexible
✓ High accuracy and repeatability
- Second iteration
Transmitter | Receiver
Known phantom | Unknown phantom

Collaborative robot

# Last year's iteration

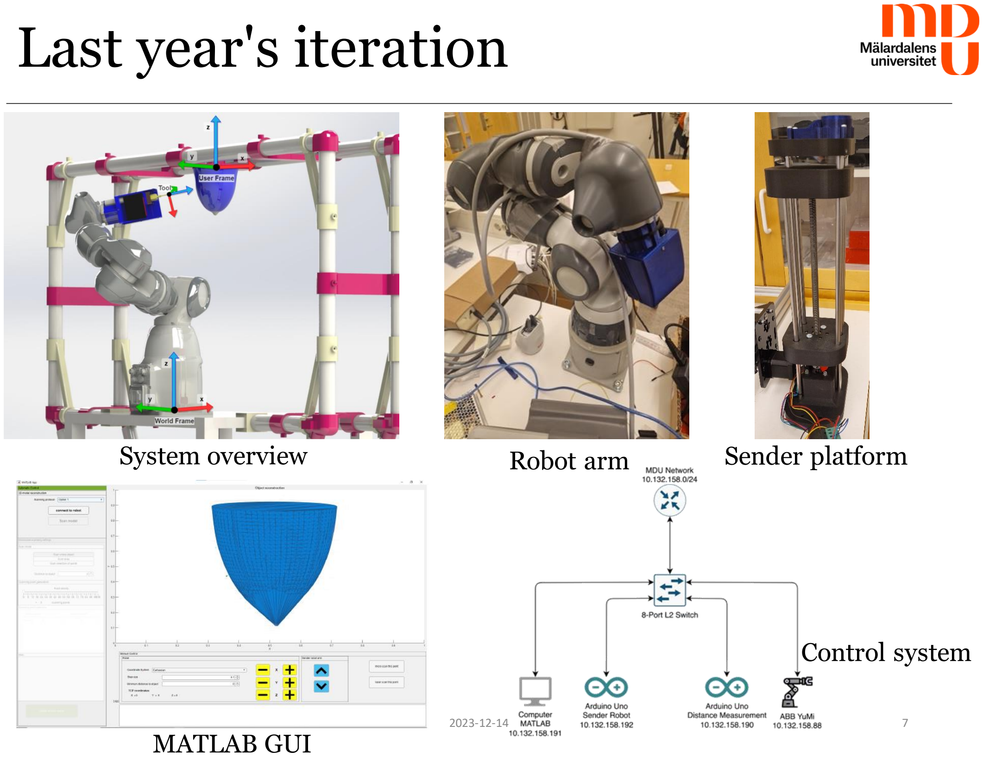
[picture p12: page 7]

Robot arm | Sender platform

MATLAB GUI

System overview

Control system

# Hardware – System overview

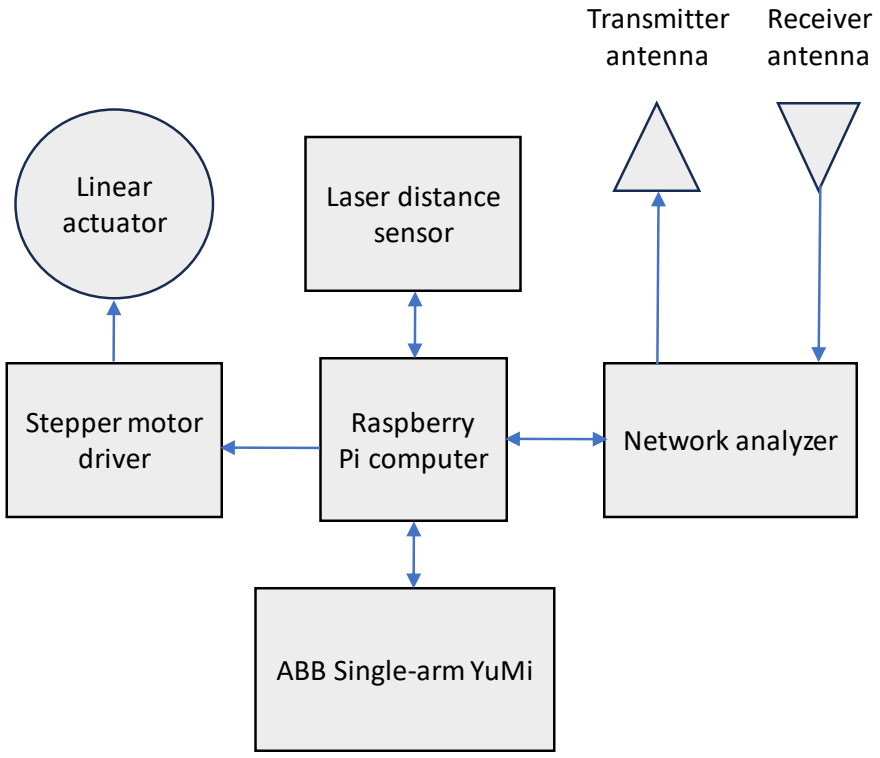
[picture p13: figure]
Raspberry Pi computer; Laser distance sensor; Network analyzer; ABB Single-arm YuMi; Stepper motor driver; Linear actuator; Transmitter antenna; Receiver antenna

# Hardware

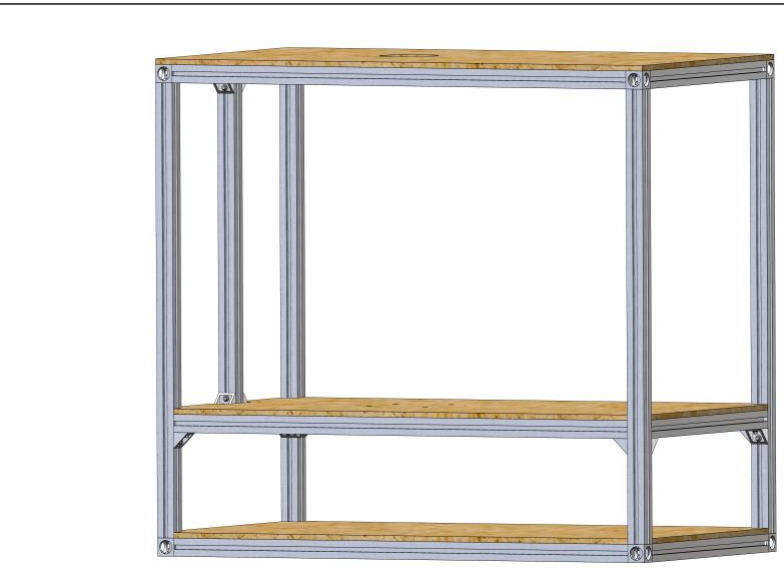
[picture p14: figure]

## - Frame

# Hardware

## - Frame

## - Single-arm YuMi with controller

# Hardware

## - Frame

## - Single-arm YuMi with controller - Breast phantom

# Hardware

## - Frame

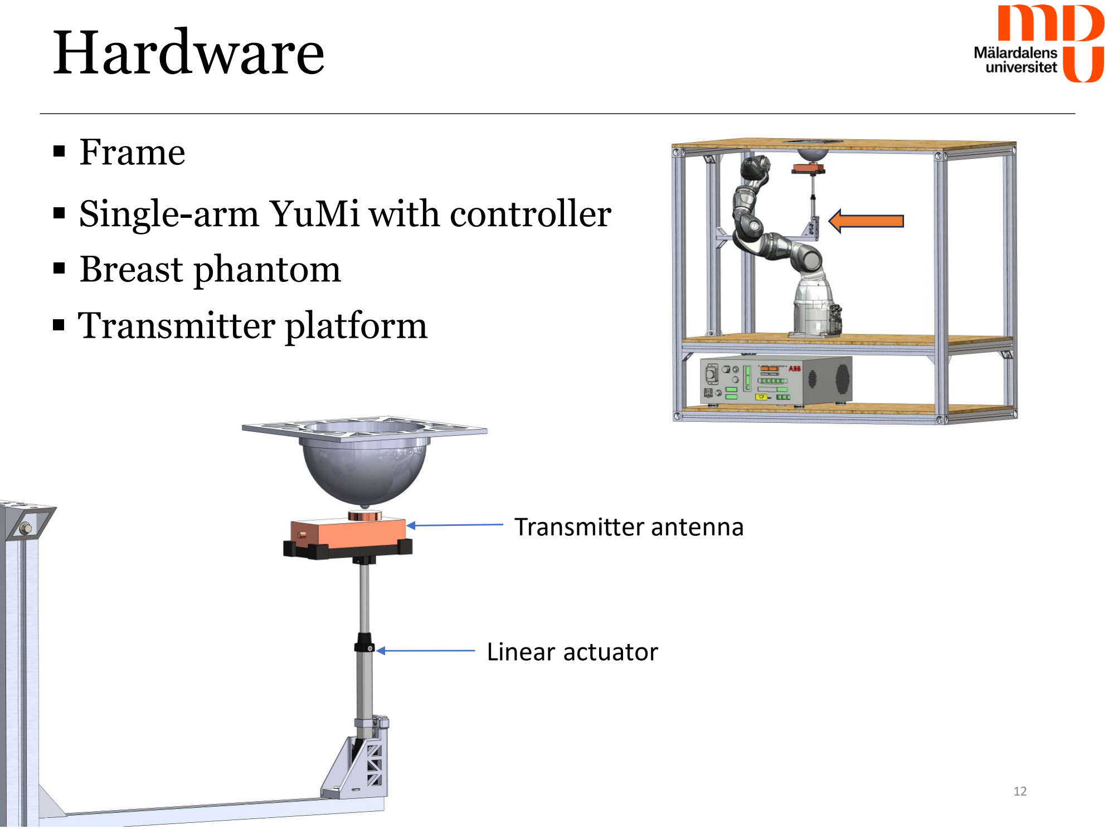
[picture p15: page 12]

Linear actuator

Transmitter antenna

## - Single-arm YuMi with controller - Breast phantom - Transmitter platform

# Hardware

## - Frame

Receiver antenna

Laser distance sensor

## - Single-arm YuMi with controller - Breast phantom

## - Robot end effector

## - Transmitter platform

# Hardware

## - Frame

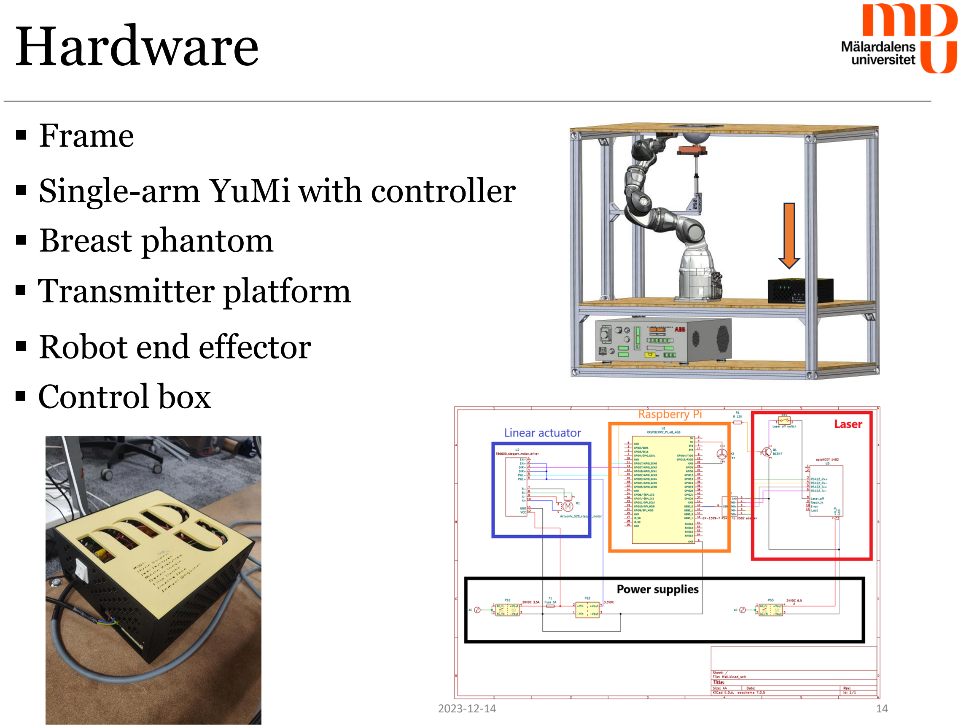
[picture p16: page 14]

## - Single-arm YuMi with controller - Breast phantom

## - Robot end effector - Control box

## - Transmitter platform

# Hardware

## - Frame

## - Single-arm YuMi with controller - Breast phantom

## - Robot end effector - Control box

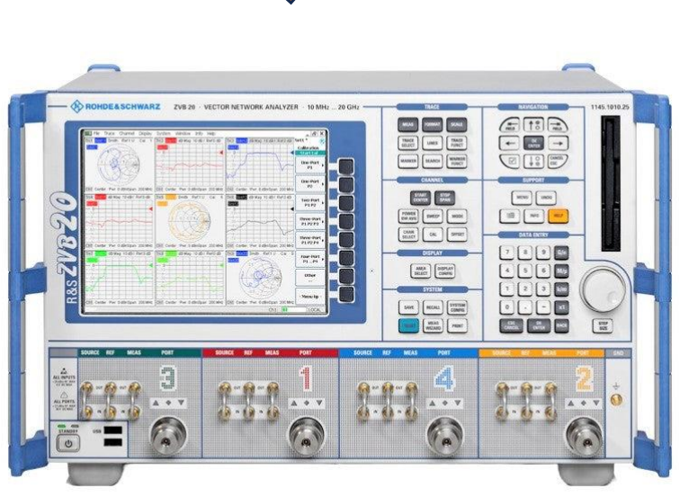
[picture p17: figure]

## - Network analyzer

## - Transmitter platform

# Software components

# RAPID

?

YuMi movement
?

Surface reconstruction
?

Microwave measurements
?

GUI
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

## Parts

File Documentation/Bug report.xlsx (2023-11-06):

Where: | Bug description: | Expected result: | Actual result: | Authors: | Date for last update: | Comments: | Status:
[Where or which part the error or bug found] | [Describe the bug.] | [Describe the expected result.] | [Enter the actual result.] | [Person who wrote this test case.] | [Date when this test case was last updated.] |  | Fixed
[Where or which part the error or bug found] | [Describe the bug.] | [Describe the expected result.] | [Enter the actual result. ] | [Person who wrote this test case.] | [Date when this test case was last updated.] |  | Error

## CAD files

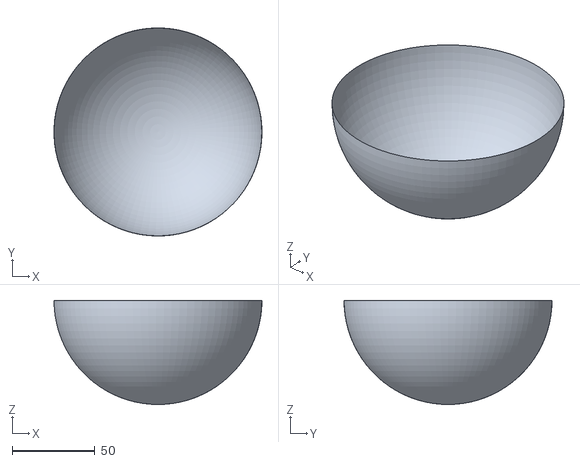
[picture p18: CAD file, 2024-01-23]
stl_files/SimpleBreast_R62_centered_nonipple_surface_origin.STL
126.0 x 126.0 x 63.0

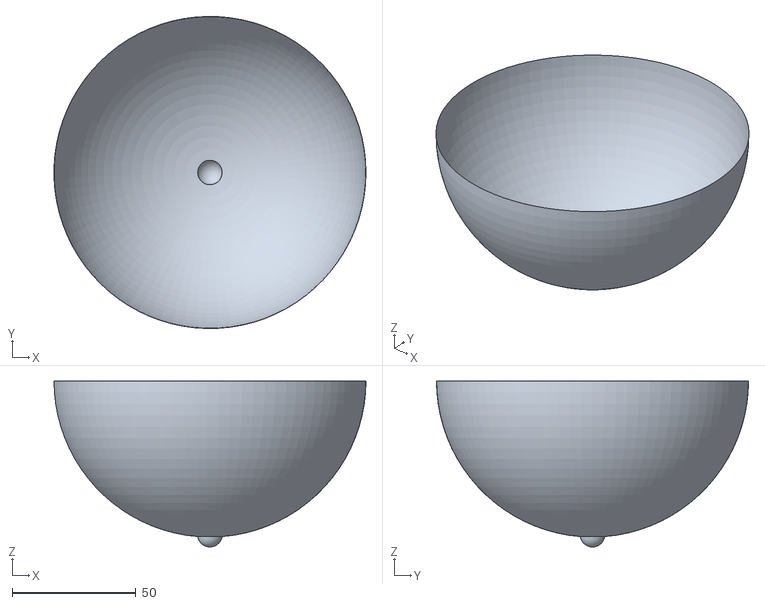
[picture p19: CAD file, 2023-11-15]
stl_files/SimpleBreast_R62_centered_surface_origin_aligned.STL
126.0 x 126.0 x 67.0

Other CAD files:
stl_files/SimpleBreast_R62_centered_surface.STL

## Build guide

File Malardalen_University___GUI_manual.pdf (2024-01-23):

## Mälardalen University School of Innovation Design and Engineering

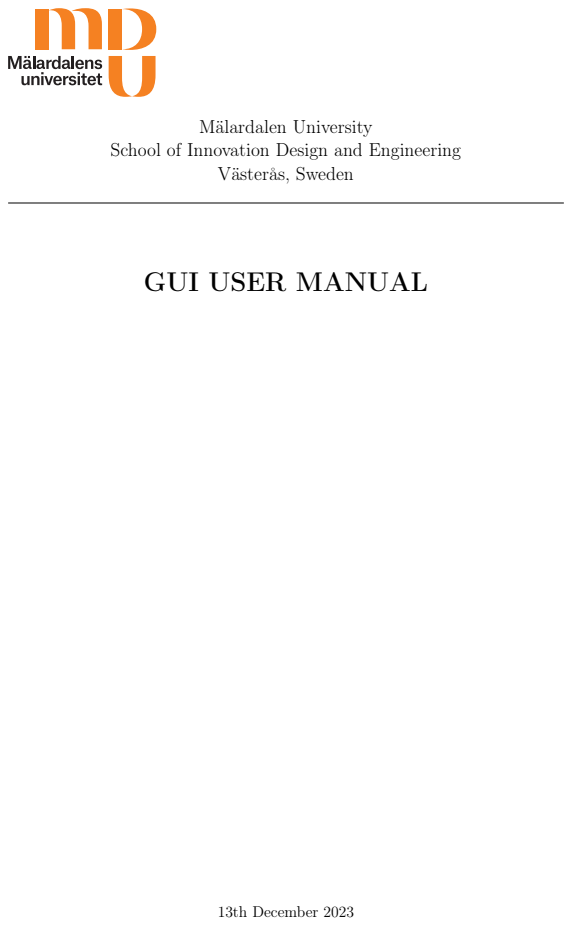
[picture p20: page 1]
Västerås, Sweden; 13th December 2023

GUI USER MANUAL

CONTENTS | CONTENTS

## Contents

1. GUI overview | 1
2. Scan Button | 1
3. Stop Button | 6
4. Save Button | 7
5. Load Button | 7
6. Calibration Button | 7
7. Manual Control | 8
8. Log | 9
9. 3D reconstruction | 9
10.Network viewer | 10

2. SCAN BUTTON

## 1. GUI overview

This GUI is not dynamic adjustable. Therefore, you need a big screen for display all functions. Run MainProgram.py for run the GUI.
It is able to perform cylindrical scan. When you use halve sphere scan, your robot will have a collision with linear actuator. Same problem in microwave scanning when you want to scan the point on the bottom.

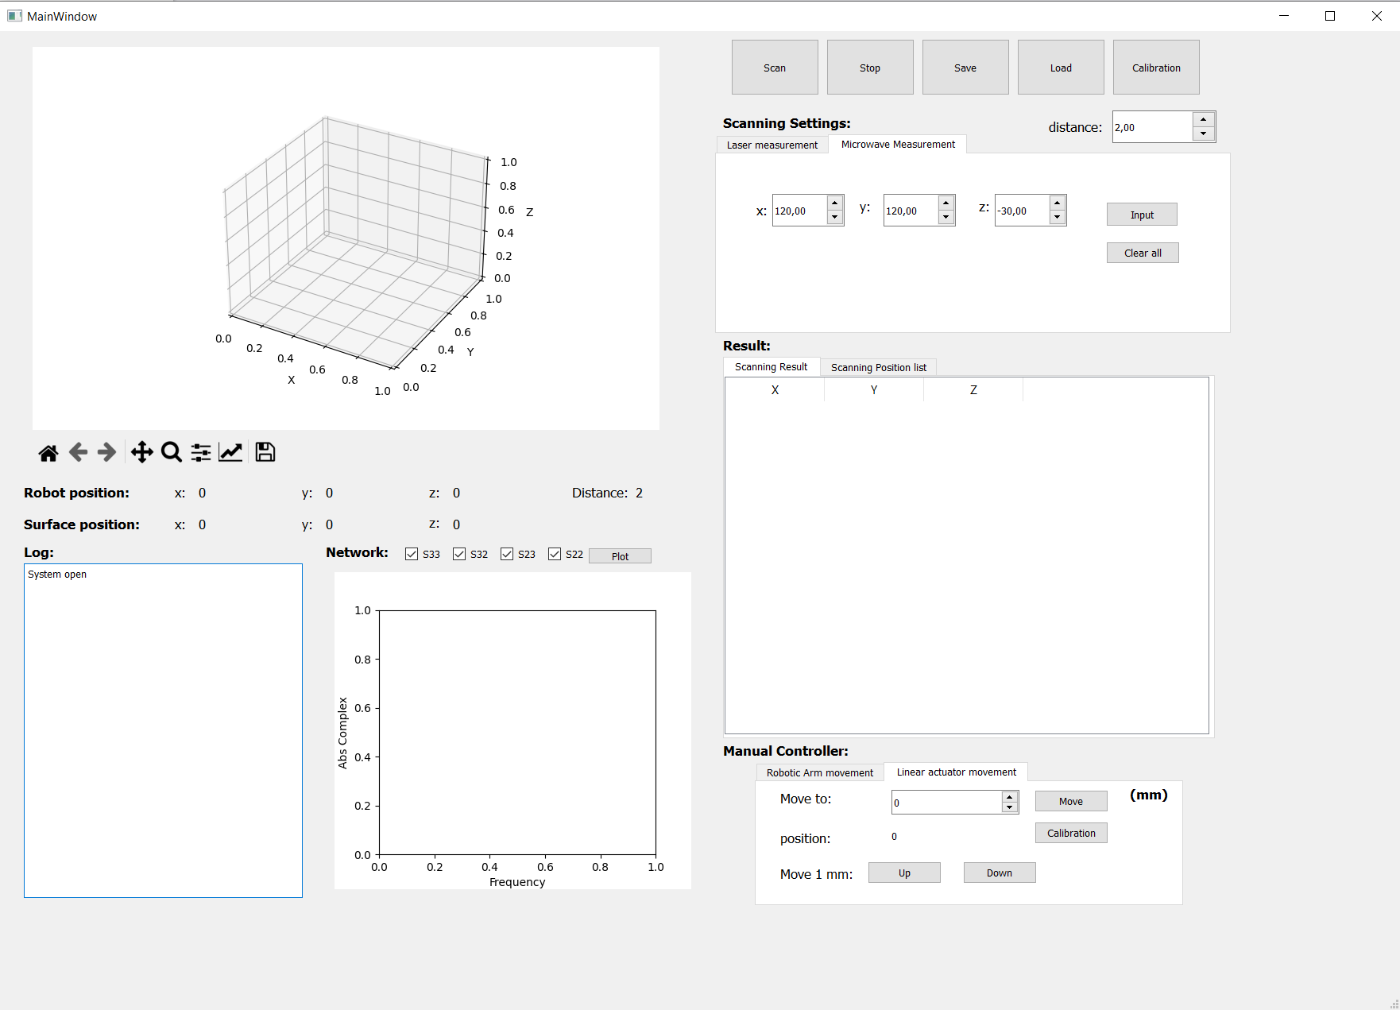
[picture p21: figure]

## 2. Scan Button

Perform scanning based on which tab is activating in Scanning Settings when user press the scan button. When scanning, other buttons about robot arm will be disable expect stop button. The result will be save in the Scanning result table in Result and plot in the Scanning viewer.

2. SCAN BUTTON

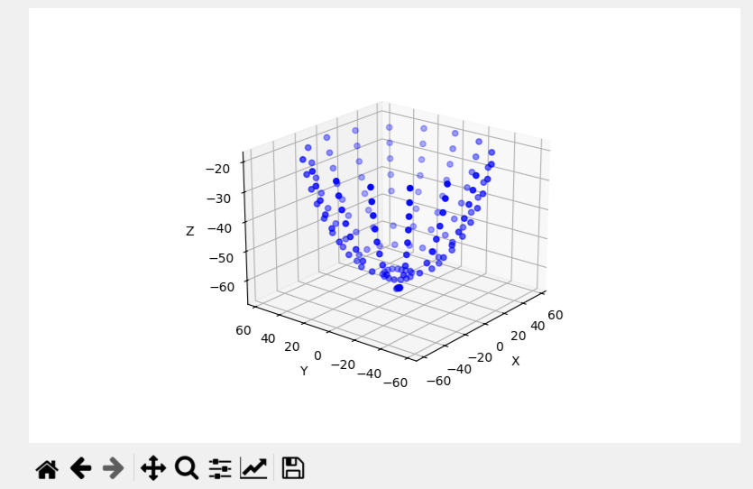
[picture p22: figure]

Figure 1: Scanning viewer

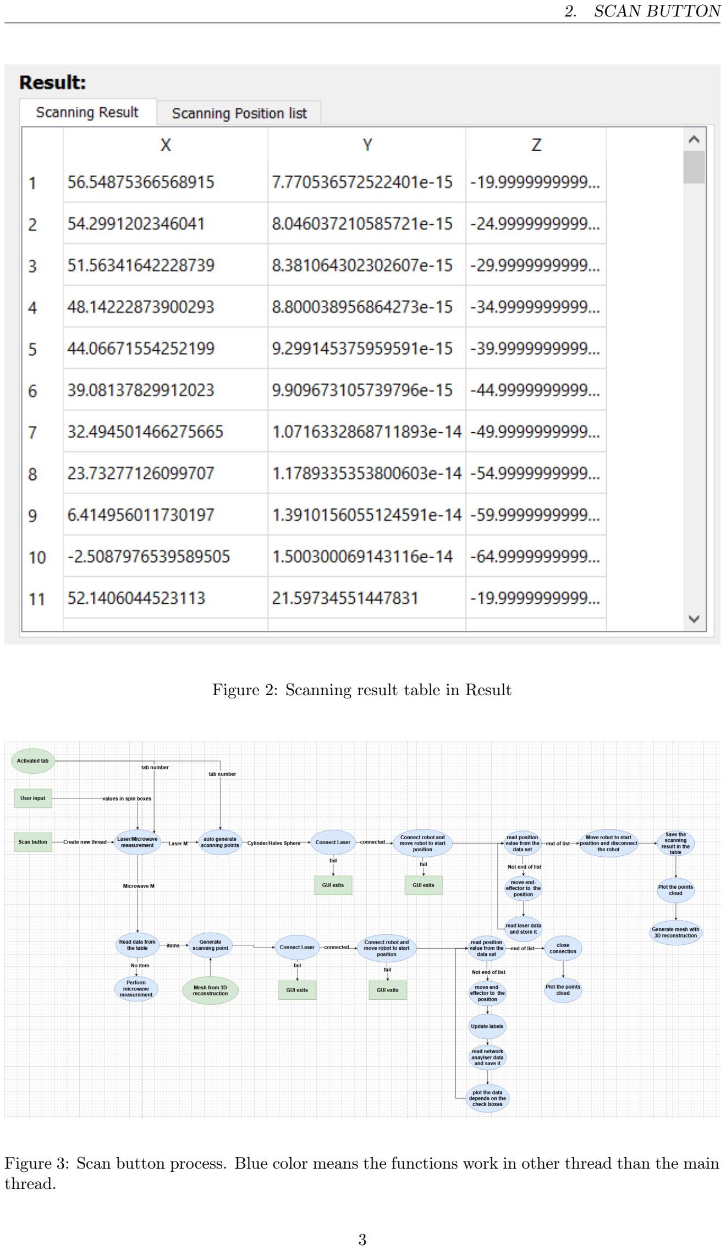
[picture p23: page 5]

2. SCAN BUTTON

Figure 2: Scanning result table in Result

Figure 3: Scan button process. Blue color means the functions work in other thread than the main thread.

2.1. Laser scanning | 2. SCAN BUTTON

### 2.1. Laser scanning

When this tab is activating, the robot will preform a scanning by auto generate scanning points from values in spin boxes.
Meaning of spin boxes:
- circle_radius = Radius of the cylinder
- azimuthPoints = Number of points in the azimuth angle
- zMin = Lowest point of the cylinder
- offset = Offset in the z-axis

2.1..1 Cylinder Scan

When this tab is activating, the robot will preform a cylindrical scanning by auto generate scanning points.
Meaning of spin boxes:
- z_stepsize = Number of mm between each z-plane
- laser_angle = The angle of the end effector to point the laser (between +90 and -90)

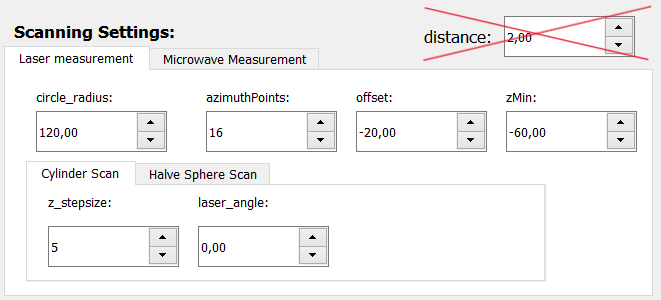
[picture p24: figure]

Figure 4: A cylindrical scanning setting

2.1..2 Halve Sphere Scan

Warning: Don’t use this function when there is a linear actuator on the bottom of the object. When this tab is activating, the robot will preform a halve spherical scanning by auto generate scanning points.
Meaning of spin boxes:
- elevationPoints = Number of points in the elevation plane

2.2. Microwave measurement | 2. SCAN BUTTON

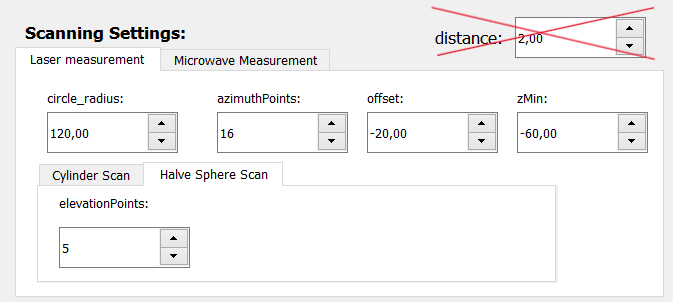
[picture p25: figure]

Figure 5: A halve spherical scanning setting

### 2.2. Microwave measurement

Warning: When you want to scan the point on the bottom, collision with linear actuator happen. When this tab is activating, the robot will preform a scanning by reading the values in the Scanning Position list. If there is no item in the table, then it will start microwave measurement without moving. After measurement, robot position data will be display in Robot position and surface position labels. Also, the result of the network analyser will be display in the network viewer.
Buttons:
- Input = Read the values in the x, y, z spin box. Recalculate the coordinates to a point on the surface of the object. And print the point in the table and scanning viewer. (Warning: If there are no mesh when you pressed the button, the GUI will be crashed. Make sure you start a laser scanning or load a CSV file before the action. )
- Clear all = Remove all items in the Scanning Position list table.
- distance spin box = how far between the surface of object and the antenna in mm.

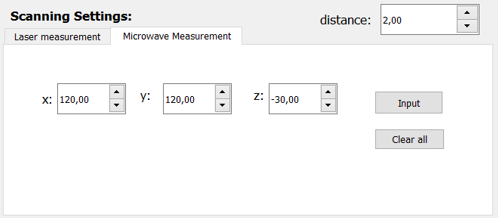
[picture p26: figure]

Figure 6: When microwave measurement tab is activating

3. STOP BUTTON

Figure 7: Latest scan point will display in labels if you scan the object with manual inputs.

Note:

- You are able to change the value in the table by double click the value.
- This scanning using the mesh data from 3D reconstruction. The mesh data generated by using values in results. There, you must scan the object or load data from csv using Load button.

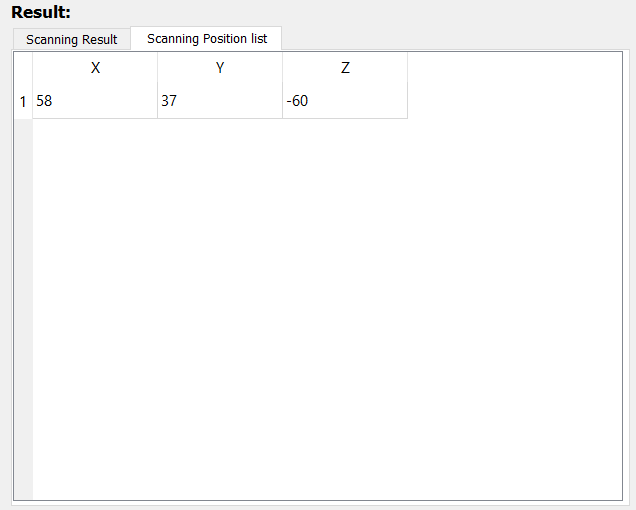
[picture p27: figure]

Figure 8: Manual inputs in Scanning Position list

## 3. Stop Button

Stop the scanning, calibration or movement of robot.
Note:
- When you perform stop action, this means the thread of scanning or calibration will be terminate. But the command are still in the Yumi Controller. So the Yumi will perform actions until end of the command. Use the red stop button in the Yumi Controller if you need to stop immediately.

6. CALIBRATION BUTTON
- Even you perform stop action, the connection between Raspberry Pi and Yumi controller is not disconnect. Therefore, you need to restart the GUI program to disconnect. Therefore, you are not able to use any function that move the Yumi after you pressed stop button.

Figure 9: Stop button process. Blue color means the functions work in other thread than the main thread

## 4. Save Button

Save items in the Scanning Result table in Result as a csv file.

Figure 10: Save button process

## 5. Load Button

Read data from a csv file and insert to the Scanning Result table. It will also plot the point cloud base on the data and perform a 3d reconstruction.

Figure 11: Load button process

## 6. Calibration Button

Warning: It cause problem when robotic arm have too many cables.
Perform a calibration scanning and update the quaternions which are used for scan the object. Note:

7. MANUAL CONTROL
- The standard quaternion is [9.99954527e-01, 9.41712207e-03, 1.50357889e-03, 9.45543129e-06] in ClassGUI.py. This number is save in a csv file called quaternions.csv in GUI folder. After calibration, the value will be updated.

Figure 12: Calibration button process. Blue color means the functions work in other thread than the main thread.

## 7. Manual Control

Functions for control the robotic arm and linear actuator manually.

### 7.1. robotic arm movement

The principal of robotic arm movement is to able perform small movement +-1 mm. But it always go back to the start position and then go to the specific position. Therefore, it is not good to use it. Use manual input scanning points instead. It also use same distance spin box same as the manual input scanning points.

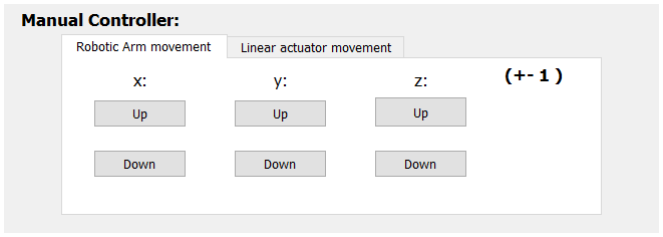
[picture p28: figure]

Figure 13: Manual robot controller

Figure 14: Robot control buttons process. Blue color means the functions work in other thread than the main thread.

### 7.2. Linear actuator movement

Functions for control the linear actuator. You are able to move the linear actuator +-1 mm or go to specific position by use Move button. Also, before you use the controller, you need to move the linear actuator down to bottom (the zero position), and then press calibration button in the tab to let the program know the linear actuator is on the zero position.
Buttons:

9. 3D RECONSTRUCTION
- Move = move to specific position using input in the spin box.
- Calibration = set the current value to 0
- Up = move linear actuator up 1mm
- Down = move linear actuator down 1mm

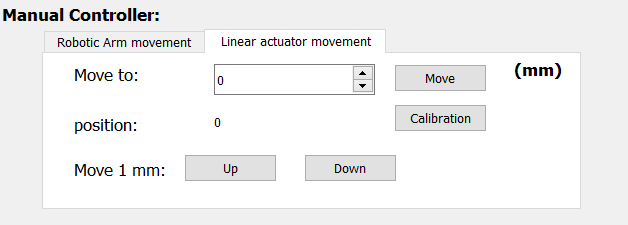
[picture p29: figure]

Figure 15: Linear actuator

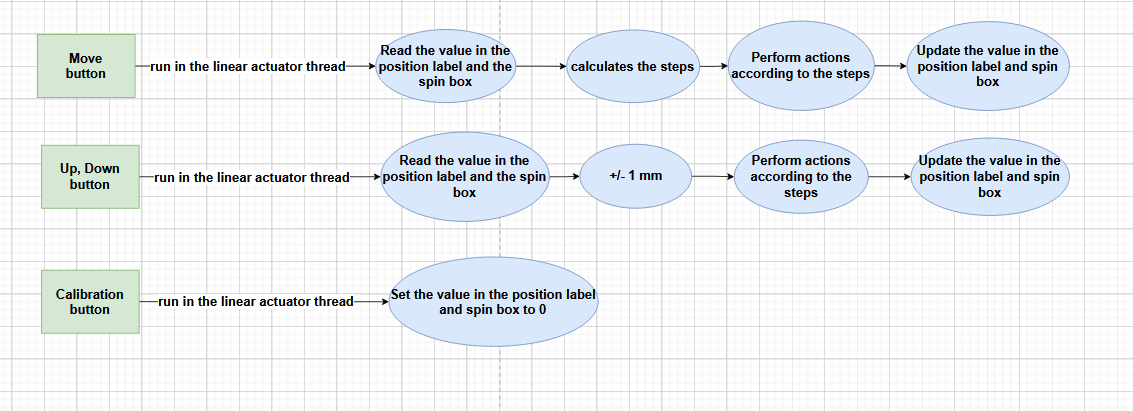
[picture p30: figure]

Figure 16: Linear actuator buttons process. Blue color means the functions work in other thread than the main thread.

## 8. Log

A text box that use for display messages.

## 9. 3D reconstruction

Because Raspberry pi does not does not support the draw function in open3D. Therefore, this functions is not available. But other functions like create mesh works. You can save the mesh to a .obj file by change the code in ClassGUI.py. And if you do, the 3D reconstruction data saves in a file called meshNew.obj.

10. NETWORK VIEWER

## 10. Network viewer

A viewer for display the result of network analyser. It is also automatically save the result in the mw_data folder. Which result will be display base on which checkbox you had checked. Buttons:

- plot = read a csv file in mw_data and plot it in the viewer

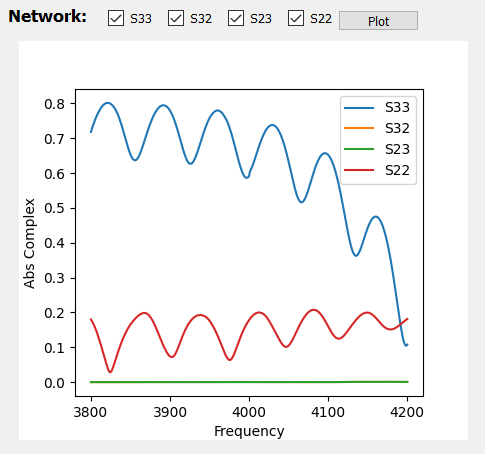
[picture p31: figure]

Figure 17: Network viewer

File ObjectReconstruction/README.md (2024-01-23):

# [IMPORTANT] 
This guide will help the user run scripts related to object reconstruction.
The program requiers Open3d which is a python library for handling 3D data processing. 
Open3d in turn requires python 3.10- . To install open3d make sure python 3.10 is installed, then run "pip3.10 install open3d"
More information on Open3d can be found on the official website : http://www.open3d.org/

You can also run "pip3.10 install -r requirements.txt" to install all required packages for the micro Tomography project.

## [main.py]:
Open the file main.py

The fileName variable holds the path to the file where the data is located. 
Change this variable name to the correct file.

In the file load_cad_file.py enter the correct name of the choosen CAD File. 

the variable test changes which surface reconstruction to run, either Poisson or Delaunay.

re_resolution and gt_resolution indicates the Depth of the oc tree of the poisson surface reconstruction. Change this for different results.

Run the program.

## [surface_reconstuction.py]:

### [delaunay]:
This algorithm takes one input argument. 
Points, which is the desired point cloud. 
The program will return the delaunay triangulation mesh object.

### [alpha_shape]:

This algorithm takes two input arguments.
Points which is the desired point cloud and Save which is a bool where True indicates that the mesh should be saved. Or False which indicates that it should not be saved.

Inside the script there are four important variables which desicdes the results of the algorithm.

alpha : This changes the alpha parameter, which is important for the alpha_shape. Basically it's the radius of the sphere that "rolls" around each point.
norm_Radius : The radius of the circle which decides what points should be used to approximate the normal
norm_NN : how many points inside the circle with radius norm_Radius should be used to approximate the normal.
orient_Norm_Knn : Descides the direction of the mesh. Higher value the more normals are used to change all normals to the same direction.

The script returns a special open3D mesh obj.

### [ball_pivoting]:

This algorithm takes two input arguments.
Points which is the desired point cloud and Save which is a bool where True indicates that the mesh should be saved. Or False which indicates that it should not be saved.

There is one important variable inside this script. 

radii : This includes the list of radii which are used in the ball_pivoting algorithm. Basically it's the radii of the sphere's that rolls around each point.

The script returns a special open3D mesh obj.

### [poisson_surface_reconstruction]:

This algorithm takes three input arguments.
Points which is the desired point cloud and Save which is a bool where True indicates that the mesh should be saved. Or False which indicates that it should not be saved and re_resolution which decides the depth of the oc tree used in the poisson algorithm.

Inside the script there are five important variables which desicdes the results of the algorithm.

mask : removes all points in the point cloud above the mask value. It's only used if needed
norm_Radius : The radius of the circle which decides what points should be used to approximate the normal
norm_NN : how many points inside the circle with radius norm_Radius should be used to approximate the normal.
orient_Norm_Knn : Descides the direction of the mesh. Higher value the more normals are used to change all normals to the same direction.
bounding_additions : Adds the values (mm) to the bounding box to remove unwanted meshes outside of the point cloud. (This might be needed depending on what object is reconstructed. Poisson forces itself to create a watertight mesh, and if the point cloud is not meant to form a watertight mesh(i.e there are areas where alot of points are missing ) the mesh will look a bit weird. This will basically remove the weird part of the mesh.)

The script returns a special open3D mesh obj.

### [how to draw]:

uncomment the line : o3d.visualization.draw_geometries([pcd,mesh], mesh_show_back_face=True)
If there's no line like that, just add it. 
the pcd part draws the point cloud, the mesh part draws the mesh

This works for all except delaunay. If you need to print delaunay it's trivial using python libraries.

## [choosen_points_microwave.py]:
This file includes 3 different functions.
I suggest using "get_points" since this is most optimal for finding the correct point on the mesh.
The difference lies within how it raycasts. "get_point()" uses a normal that points directly to the [0,0,z] point, whilst the function "ray_cast_points()" finds the closest point on the mesh(Which does not always lie on the same Z as the whished point.).
The last function "get_quaternions()" simply computes the quaternions from the normals.

The function calls looks like the following : 
get_points(recon_mesh, choosenPoints, distance_from_mesh):
ray_cast_points(recon_mesh, choosenPoints, distance_from_mesh):

Where the arguments are explained as follows:
recon_mesh : The reconstructed mesh (i.e from scanned point cloud.).
choosenPoints : A list of arbitrary points (Where the you want the microwave antenna to be placed.).
distance_from_mesh : The distance in mm from the mesh where you want the antenna to be placed.

The script returns closestPoints, quaternion,closestNormals where : 
closestPoints : is a list of the points where the antenna should be placed. 
quaternion : a list of quaternions for the end effector. 
closestNormals : is a list of the normals that correlates to the points in closestPoints list.

### [plot_chosen_points.py]

This script works the same as choosen_points_microwave.py but it is used to plot the points in 3D.
It takes the same input arguments.

## [trace_error.py]:

The script takes five input arguments.

GT_mesh : The reconstructed ground truth mesh. (i.e CAD object mesh)
reconstruced_mesh : The reconstructed mesh. (from scanned point cloud)
test : indicates wether or not delaunay triangular mesh should be used(1 for poisson,ball_point or alpha_shape, 2 for delaunay)
points : point cloud
save : true of false

The script will raycast from each point in GT_mesh and compute the distance to the reconstructed_mesh.

The script will also plot a 3d point cloud with colours indicated based on the distances of each point in the GT_mesh. 
The point cloud shown will be the GT_mesh's point cloud and the colours indicate the distance to the reconstructed_mesh.

The script will return a the average distance. 

## [move_pointcloud.py]:

This script takes one input argument. 

points : a point cloud (i.e scanned data)

Centers the pointcloud around [0,0,0]
returns the centered point cloud.

## [interpolate_up.py]: 

The script takes two input arguments. 

points : a point cloud (i.e scanned data)
step_size : a step size in mm

The script copies the top "row" of the scanned point cloud (In our case it's the top circle of the scanned data. I.e all aizumuth points in the with the highest Z value.) 15/stepsize times. 

(It's used to make the poisson surface reconstruction better, since poisson does not like that there are no scanned points on the top of the breast.)

## [Misc]:

There are some scripts that are not used in the final project. 
They include some spline scripts which can be used to interpolate the data to get a higher amount of data points.
It also includes some Reshape scripts which can be used to reshape the data (This was used in the beginning when we were using data from previous years project with a different data structure.)

read_save_csv.py is used to read or save csv files.

load_cad_file.py is used to load a cad file it's used in the main.py script and explained in that section of this readme.

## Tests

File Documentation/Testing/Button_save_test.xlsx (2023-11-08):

Application: | Step: | Test Description: | Expected result: | Actual result: | Authors | Date for last update | Comments: | Status:
Save Button | 1. | Click the "save" button | A windows pop up | A windows pop up | Jiantao Shen | 2023-09-29 |  | success
 | 2. | Name the save.csv and save it | A save.csv file was created in the chosen path | A csv file was created in the choosen path | Jiantao Shen | 2023-09-29 |  | success
 | 3. | Click the "load" button | A windows pop up | A windows pop up | Jiantao Shen | 2023-09-29 |  | success
 | 4. | Choose the save.csv and open it | The Viewer on the left shows the points cloud. It shows the same plot as before. | The Viewer on the left shows the points cloud. It shows the same plot as before. | Jiantao Shen | 2023-09-29 |  | success

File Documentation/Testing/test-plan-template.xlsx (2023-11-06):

Application: | Step: | Test Description: | Expected result: | Actual result: | Authors | Date for last update | Comments: | Status:
[Name of the application being tested] | 1. | [Describe the test.] | [Describe the expected result.] | [Enter the actual result. If the actual result matches the expected result then the fields should match.] | [Person who wrote this test case.] | [Date when this test case was last updated.] |  | success
 | 2. | [Describe the test.] | [Describe the expected result.] | [Enter the actual result. If the actual result matches the expected result then the fields should match.] | [Person who wrote this test case.] | [Date when this test case was last updated.] |  | fail

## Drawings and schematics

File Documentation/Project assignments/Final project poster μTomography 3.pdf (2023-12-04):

## Motivation and goal:

# Microwave Imaging for Breast Cancer Detection: A

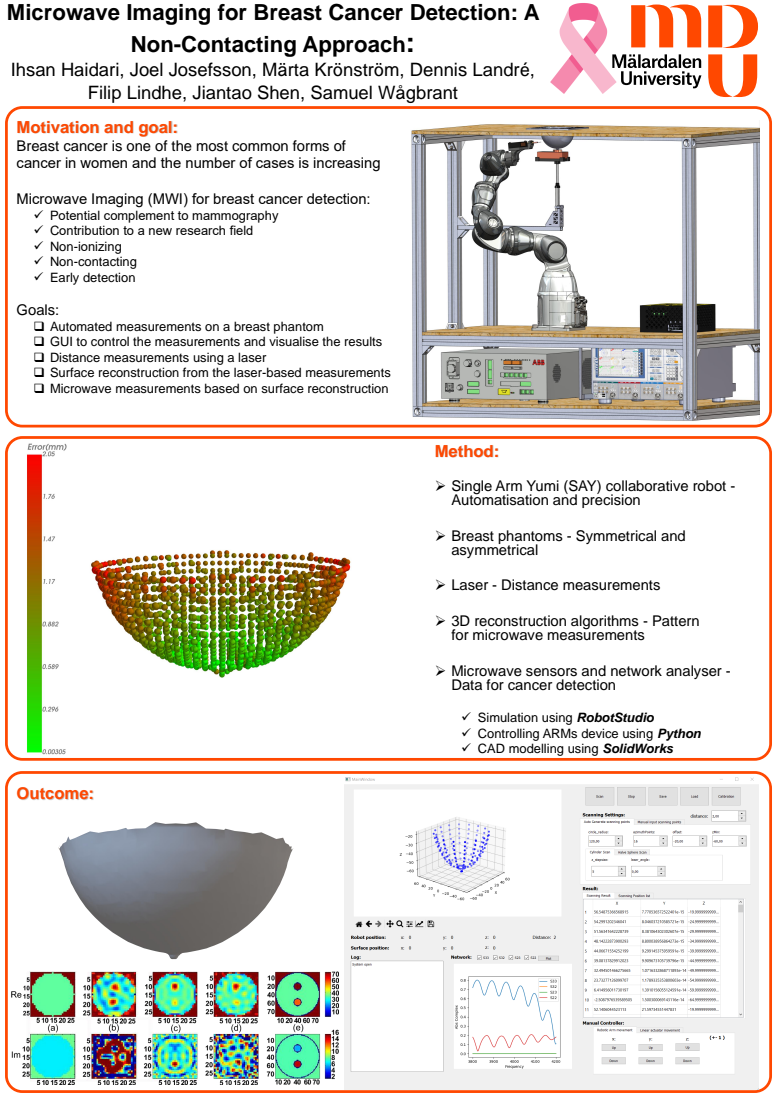
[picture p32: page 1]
Method:; Outcome:

Non-Contacting Approach:

Ihsan Haidari, Joel Josefsson, Märta Krönström, Dennis Landré,

Filip Lindhe, Jiantao Shen, Samuel Wågbrant

Breast cancer is one of the most common forms of
cancer in women and the number of cases is increasing

Microwave Imaging (MWI) for breast cancer detection:
✓ Potential complement to mammography
✓ Contribution to a new research field
✓ Non-ionizing
✓ Non-contacting
✓ Early detection

Goals:
❑ Automated measurements on a breast phantom
❑ GUI to control the measurements and visualise the results
❑ Distance measurements using a laser
❑ Surface reconstruction from the laser-based measurements
❑ Microwave measurements based on surface reconstruction

➢ Single Arm Yumi (SAY) collaborative robot -
Automatisation and precision

➢ Breast phantoms - Symmetrical and
asymmetrical

➢ Laser - Distance measurements

➢ 3D reconstruction algorithms - Pattern
for microwave measurements

➢ Microwave sensors and network analyser -
Data for cancer detection

✓ Simulation using RobotStudio
✓ Controlling ARMs device using Python
✓ CAD modelling using SolidWorks

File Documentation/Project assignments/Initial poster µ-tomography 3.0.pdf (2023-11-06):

## Motivation:

## Microwave Imaging for Breast Cancer Detection:

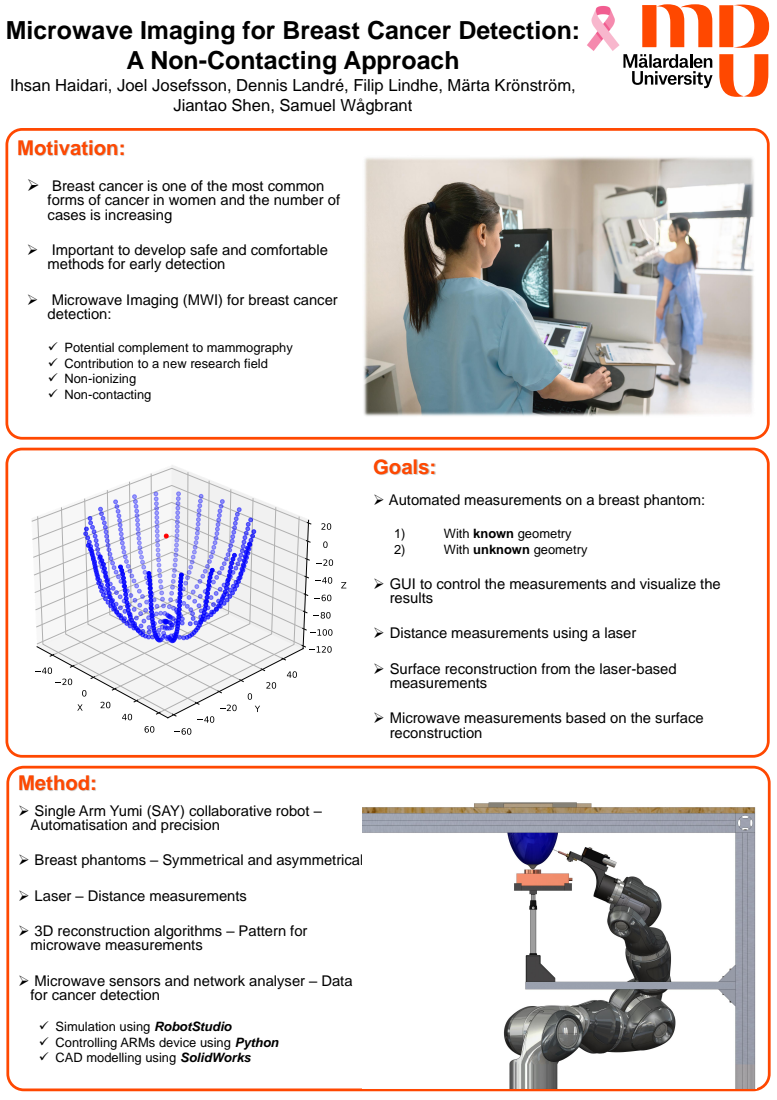
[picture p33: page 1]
Goals:; Method:

A Non-Contacting Approach

Ihsan Haidari, Joel Josefsson, Dennis Landré, Filip Lindhe, Märta Krönström,

Jiantao Shen, Samuel Wågbrant

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

➢ Important to develop safe and comfortable
methods for early detection

➢ Microwave Imaging (MWI) for breast cancer
detection:

✓ Potential complement to mammography
✓ Contribution to a new research field
✓ Non-ionizing
✓ Non-contacting

➢ Automated measurements on a breast phantom:

1) With known geometry
2) With unknown geometry

➢ GUI to control the measurements and visualize the
results

➢ Distance measurements using a laser

➢ Surface reconstruction from the laser-based
measurements

➢ Microwave measurements based on the surface
reconstruction

➢ Single Arm Yumi (SAY) collaborative robot –
Automatisation and precision

➢ Breast phantoms – Symmetrical and asymmetrical

➢ Laser – Distance measurements

➢ 3D reconstruction algorithms – Pattern for
microwave measurements

➢ Microwave sensors and network analyser – Data
for cancer detection

✓ Simulation using RobotStudio
✓ Controlling ARMs device using Python
✓ CAD modelling using SolidWorks

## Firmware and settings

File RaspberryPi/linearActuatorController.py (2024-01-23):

import RPi.GPIO as GPIO
import time

# Define GPIO pins for TB6600 control
PUL_PIN = 17  # GPIO 17 for pulse
DIR_PIN = 27  # GPIO 27 for direction
# ena_pin = 22  # GPIO 22 for enable
# total_steps_changes = 0 # Global value_ calculate the steps +1 for step up and -1 for step down


class linear_actuator:
    def __init__(self):
        GPIO.setmode(GPIO.BCM)
        GPIO.setup(PUL_PIN, GPIO.OUT)
        GPIO.setup(DIR_PIN, GPIO.OUT)
        self.total_steps_changes = 0

    # Function to calculate the number of steps needed to move a certain linear distance
    def calculate_steps(self, desired_distance, step_size=0.01):
        return int(desired_distance / step_size)

    # function to move the motor when gien the steps
    def move(self, steps_to_move):
        delay = 0.001

        for _ in range(steps_to_move):
            GPIO.output(PUL_PIN, GPIO.HIGH)
            time.sleep(delay)
            GPIO.output(PUL_PIN, GPIO.LOW)
            time.sleep(delay)
            if (
                GPIO.input(DIR_PIN) == GPIO.HIGH
            ):  # Depending on direction of the steps, it counts the amount of steps
                self.total_steps_changes += 1
            elif self.total_steps_changes > 10000:
                break

        # return total_steps_changes

    def move_to_desired_location_upwards(
        self,desired_distance_mm
    ):  # Get distance from app.py
        GPIO.output(DIR_PIN, GPIO.HIGH)  # set the direction UP

        #desired_distance_mm = float(input("Enter the desired distance (mm)")) # choosing the desired distance in mm

        steps_to_move = self.calculate_steps(
            desired_distance_mm
        )  # calculating the desired distance in steps

        self.move(steps_to_move)  # call the move function

        #GPIO.cleanup()
        # return total_steps_changes

    def move_to_zeroLocation(self):  # This function move the motor to zero location
        GPIO.output(DIR_PIN, GPIO.LOW)

        delay = 0.001

        for _ in range(self.total_steps_changes):
            GPIO.output(PUL_PIN, GPIO.HIGH)
            time.sleep(delay)
            GPIO.output(PUL_PIN, GPIO.LOW)
            time.sleep(delay)

        # GPIO.cleanup()

    def move_up_1mm(self):
        GPIO.output(DIR_PIN, GPIO.HIGH)
        delay = 0.001
        t = 100
        for _ in range(t):
            GPIO.output(PUL_PIN, GPIO.HIGH)
            time.sleep(delay)
            GPIO.output(PUL_PIN, GPIO.LOW)
            time.sleep(delay)

        # GPIO.cleanup()

    def move_down_1mm(self):
        GPIO.output(DIR_PIN, GPIO.LOW)
        delay = 0.001
        t = 100

        for _ in range(t):
            GPIO.output(PUL_PIN, GPIO.HIGH)
            time.sleep(delay)
            GPIO.output(PUL_PIN, GPIO.LOW)
            time.sleep(delay)

        # GPIO.cleanup()

    def move_actuator(self):
        while True:
            # print(total_steps_changes)
            # print("\n")

            ##For control the values between 0 < x < 10000
            if self.total_steps_changes < 0:
                self.total_steps_changes = 0
            elif self.total_steps_changes > 10000:
                self.total_steps_changes = 10000

            choice = input(
                "Enter: 1:(desired location), 2:(move to zero), 3:(up 1mm), 4:(down 1mm):, q:(quit)"
            )

            if choice == "1":

                self.move_to_desired_location_upwards()

            elif choice == "2":
                self.move_to_zeroLocation()
                self.total_steps_changes = 0

            elif choice == "3":
                self.move_up_1mm()
                self.total_steps_changes += 100

                # for every move_up function the total_steps_changes are added with 100 steps = 1mm
            elif choice == "4":
                self.move_down_1mm()
                self.total_steps_changes -= 100

            elif choice == "q":
                GPIO.cleanup()
                break

            else:
                print("Invalid input")
            # char =getch.getch()

    ## example for how the master script would look líke
    # it should be within a loop so that the total steps


if __name__ == "__main__":
    lin = linear_actuator()
    lin.move_actuator()

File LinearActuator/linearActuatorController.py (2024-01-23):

import RPi.GPIO as GPIO
import time

# Define GPIO pins for TB6600 control
PUL_PIN = 17  # GPIO 17 for pulse
DIR_PIN = 27  # GPIO 27 for direction
# ena_pin = 22  # GPIO 22 for enable

class linear_actuator:
    def __init__(self):
        #Set up
        GPIO.setmode(GPIO.BCM)
        GPIO.setup(PUL_PIN, GPIO.OUT)
        GPIO.setup(DIR_PIN, GPIO.OUT)

    # function to move the motor when gien the steps
    def move(self, steps_to_move):
        delay = 0.001

        for _ in range(steps_to_move):
            GPIO.output(PUL_PIN, GPIO.HIGH)
            time.sleep(delay)
            GPIO.output(PUL_PIN, GPIO.LOW)
            time.sleep(delay)

            if steps_to_move > 10000 or steps_to_move < 0:
                break
            elif (GPIO.input(DIR_PIN) == GPIO.HIGH):  # Depending on direction of the steps, it counts the amount of steps
                steps_to_move += 1
            elif(GPIO.input(DIR_PIN) == GPIO.LOW):
                steps_to_move -= 1

    def move_to_desired_location(self, currentdistance, desired_distance_mm, direction):  # Get distance from app.py
        if direction == 1:
            GPIO.output(DIR_PIN, GPIO.HIGH)  # set the direction UP
        elif direction == 2:
            GPIO.output(DIR_PIN, GPIO.LOW)  # set the direction Down

        steps_to_move = int(abs(currentdistance - desired_distance_mm) * 100)  # calculating the desired distance in steps

        # For control the values between 0 < x < 10000
        if steps_to_move <= 0:
            steps_to_move = 0
        elif steps_to_move > 10000:
            steps_to_move = 10000

        self.move(steps_to_move)  # call the move function

    def move_up_1mm(self, steps):
        GPIO.output(DIR_PIN, GPIO.HIGH)
        delay = 0.001
        t = 100 #100 times ON and OFF = 1mm movement

        steps = steps + 1

        if steps > 100:
            steps = 100

        for _ in range(t):
            GPIO.output(PUL_PIN, GPIO.HIGH)
            time.sleep(delay)
            GPIO.output(PUL_PIN, GPIO.LOW)
            time.sleep(delay)
        
        return steps

    def move_down_1mm(self, steps):
        GPIO.output(DIR_PIN, GPIO.LOW)
        delay = 0.001
        t = 100 #100 times ON and OFF = 1mm movement

        steps = steps - 1

        if steps < 0:
            steps = 0

        for _ in range(t):
            GPIO.output(PUL_PIN, GPIO.HIGH)
            time.sleep(delay)
            GPIO.output(PUL_PIN, GPIO.LOW)
            time.sleep(delay)

        return steps

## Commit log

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2022-09-19 Added Preliminary Study Report
    [V1.SLDPRT, V2_reel.SLDPRT]
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2022-11-03 Gets point from scanProt, moves to position, calc to surface points
    missing: First position ?? dont know why. cant move there
    Real number from Laser
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2022-11-04 PowerCrust algo.
    The powerCrust algorithm:
    As Input the algorithm wants a point cloud in either 2D or 3D (3 or 2 by how many samples you have) and will output a surface estimation trough a mesh. The option to plot is present in the code, whic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
    [aSymmetricalBreastModel.STL, symmetricalBreastModel.STL]
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2022-11-18 Remaking CAD to fit new parts
    [Base.SLDPRT, Cart.SLDPRT, Coupler insert.SLDPRT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]
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2022-11-22 File cleaning and folder structure
    [10points.csv, 11points.csv, 12points.csv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]
2022-11-22 Updated parts to fit new components
    [Base.SLDPRT, Base.STL, Cart.SLDPRT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]
2022-11-23 Updated parts to fit components + laser code
    [Base.SLDPRT, Base.STL, Cart.SLDPRT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]
2022-11-25 Fixed some issues
    [Sender robot.SLDASM, Stabilizer.SLDPRT, Threaded rod.SLDPRT]
2022-11-28 fixed sender cad + laser code
    [Coupler cover.SLDPRT, Sender robot.SLDASM]
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2022-12-02 some minor fixes + arduino holder
    [Arduino holder.SLDPRT, Coupler cover.SLDPRT]
2022-12-05 In this fill, all 3D models submited
    [181022_Holder-EndEffector.STL, 181022_Left_Lock.STL, 181022_Right_lock.STL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]
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2022-12-23 last push, mixed changes
    [Base.SLDPRT, Cart.SLDPRT, Coupler cover.SLDPRT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]
2023-01-12 put all scanning protocol files in one folder for better organization in the main branch
    [2110-102-0100-BG.SLDASM, Assembly2 IPB14050.SLDASM, CP35MHT80.stp.SLDPRT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]
2023-01-12 trying to resolve conflicts
    [aSymmetricalBreastModel.STL, symmetricalBreastModel.STL]
2023-01-12 renamed solid works folder
    [181022_Holder-EndEffector.STL, 181022_Left_Lock.STL, 181022_Right_lock.STL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]
2023-01-13 Fixed main
    [Base.SLDPRT, Cart.SLDPRT, Coupler cover.SLDPRT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]
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2023-09-14 Added user manual template
    [aSymmetricalBreastModel.STL, symmetricalBreastModel.STL]
2023-09-15 Testing document for laser
    Laser and cable connection test.
    [Laser test.xlsx]
2023-09-15 Add file for document the bugs
    [Bug report.xlsx]
2023-09-21 started a class for the laser
    [aSymmetricalBreastModel.STL, symmetricalBreastModel.STL]
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2023-09-25 Upload the GUI 1.0
    [testCSV.csv, testCSV.xlsx]
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2023-09-26 Try internal laser on and off, not working sometimes
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2023-09-29 Update bug report and add testing file
    Update the bug report.xlsx
    Add testing for load and save button
    [Bug report.xlsx, Button_load_test.xlsx, Button_save_test.xlsx]
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2023-10-04 Minor changes to code. added document
    Document compares variables in the poisson surface recon, It shows Peakmemory as well as time and normal accuracy
    [Data_SurfaceRecon.xlsx]
2023-10-04 Minor code changes. Added document #2
    Added document that compares computation time of the different algorithms
    [AlgorithmComparison.xlsx, Data_SurfaceRecon.xlsx]
2023-10-06 GUI 1.2 Update
    Add 3D - reconstruction code
    Change save and load .csv to save and load .mat
    Minor change of codes
    [aSymmetricalBreastModel.STL, symmetricalBreastModel.STL]
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2023-10-09 Added raytracing to measure error between two meshes.
    WPI
    [Symmetric-221015.STL]
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2023-10-12 Changes to code. Added visualization of error in 3D
    [Symmetric-221015.SLDPRT, Symmetric-221015.STL, Symmetric-test.STL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]
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2023-10-17 Update GUI 1.3
    Add Calibration button
    Update with new 3D reconstruction code
    Update minor code and fix minor problem
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2023-10-19 Save to csv file functionality
    [1stteset.csv, 2ndtest.csv]
2023-10-20 Added data files to test repetability
    [1stteset.csv, 2ndtest.csv, file0.csv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]
2023-10-20 File relocation and update the code
    Relocate all files
    Update with newest Yumi code
    Minor code changes
    [testCSV.csv]
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2023-10-24 Added test data with transistor on laser
    [file0.csv, file1.csv, file2.csv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]
2023-10-24 Added test files with more data points in the z-axis and more azimuth points
    [fileAdditionalDataPoints0.csv, fileAdditionalDataPoints1.csv, fileAdditionalDataPoints2.csv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]
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2023-10-25 Test data with additional rawdata
    [file0.csv, file1.csv, file2.csv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]
2023-10-25 Added rawfile with laser measurement
    [rawfile0.csv]
2023-10-25 Added file with reversed order
    [reverseRawfile0.csv]
2023-10-25 Data with end azimuth points
    [endAzumuthDatapoints.csv]
2023-10-25 Remove old content
    Remove old contents because wrong manipulate
    [181022_Holder-EndEffector.STL, 181022_Left_Lock.STL, 181022_Right_lock.STL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]
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2023-10-27 Test data with base of robot
    [fileBaseOfRobot.csv]
2023-10-30 Calibration data points with asymmetrical points
    [calibrationTest0.csv]
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2023-11-01 Change back to save and load csv file
    [testCSV.csv, testCSV.xlsx]
2023-11-01 Minor changes.
    Change : Added ability to select points, then choose the closest points on the mesh.
    [deltaData.csv]
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2023-11-02 Added test made after abbsacc
    [calibrationAfterAbsacc.csv]
2023-11-03 Update with newest Yumi Code
    This code is for try if the GUI is possible to run in the simulation
    [Bug report.xlsx, calibrationAfterAbsacc.csv, calibrationTest0.csv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]
2023-11-03 Update some code in GUI
    Still cannot run in the simulation because Kinematic Error.
2023-11-03 Minor changes
    Changed file names, function names and moved some stuff from main.
    [file.csv]
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2023-11-06 Fixed an error on calibration TCP.
2023-11-07 Samuel is responsible for this commit
    [calibrationTest0.csv, file0.csv, file1.csv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]
2023-11-07 Added a main for testing the parts we have so far.
    Chaged some files to solve problem with relative imports. Fixed some errors in robot control file.
    Uploading this now to test on the Raspberry Pi, will add some improvements later (inputs can be floats and controling the max/min for some of the inputs).
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2023-11-07 Fixed so everything works with main, saving files
    [testNewest.csv, testr.csv]
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2023-11-13 Added scan test data with joel calib
    [test13_11-09_45-joel_084.csv]
2023-11-13 Have fixed a bug for user inputs (laser angle).
2023-11-13 Added new testfile with correct quats
    [13_11-10_24-Joel-084.csv]
2023-11-13 32 azimuth 2mm difference in z plane -15 to -67, 832 poibts
    [13_11-11_02-Joel_084.csv]
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2023-11-14 here you go philip
    [SimpleBreast_R62_centered_surface.STL]
2023-11-15 Minor changes + data
    [23-11-15:09:34-Joel.csv]
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2023-11-15 Minor changes
    Removed translate from load_cad_file
    Added plot axis in trace_error
    [SimpleBreast_R62_centered_surface_origin_aligned.STL]
2023-11-15 remove files that have not been tested together/test files
    [13_11-10_24-Joel-084.csv, 13_11-11_02-Joel_084.csv, 23_11_15_09_34_Joel.csv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]
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2023-11-15 Nipple area point cloud
    [nipplearea.csv]
2023-11-15 Nipple with 10x10 area
    [nipple2.csv]
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2023-11-16 Check robot coordinates until it has reached the point + nipple5
    [nipple5.csv]
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2023-11-16 Data with 32 azi, 2mm diff, -67 min joels quats
    [2023-11-16-1354-joel.csv]
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2023-11-21 changes to test all parts of the system
    [2023-11-20-13_10-modified_coords2.csv, 2023-11-20-13_51-test1.csv]
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2023-11-22 Added function that interpolates the point cloud up in Z axis
    This fixes an issue where the top of the mesh was a little off. It was off due to the way poisson works, since it tries to make a watertight mesh and the top of the breast has no points it gets funky.
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2023-12-06 QtextCursor error
    [test.csv, test.csv.csv]
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2023-12-08 fix bugs and remove some mw_data measurement
    [2023-12-08-10_51-MW_measurement_0.csv, 2023-12-08-10_59-MW_measurement_0.csv, 2023-12-08-11_04-MW_measurement_0.csv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]
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2023-12-13 calibrate.py does not work
    [2023-12-13-10_50-MW_measurement_0.csv]
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

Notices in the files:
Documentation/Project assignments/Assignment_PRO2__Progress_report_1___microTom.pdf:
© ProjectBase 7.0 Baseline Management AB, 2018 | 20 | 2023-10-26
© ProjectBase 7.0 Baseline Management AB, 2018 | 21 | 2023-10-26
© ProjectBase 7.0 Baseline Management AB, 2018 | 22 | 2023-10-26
